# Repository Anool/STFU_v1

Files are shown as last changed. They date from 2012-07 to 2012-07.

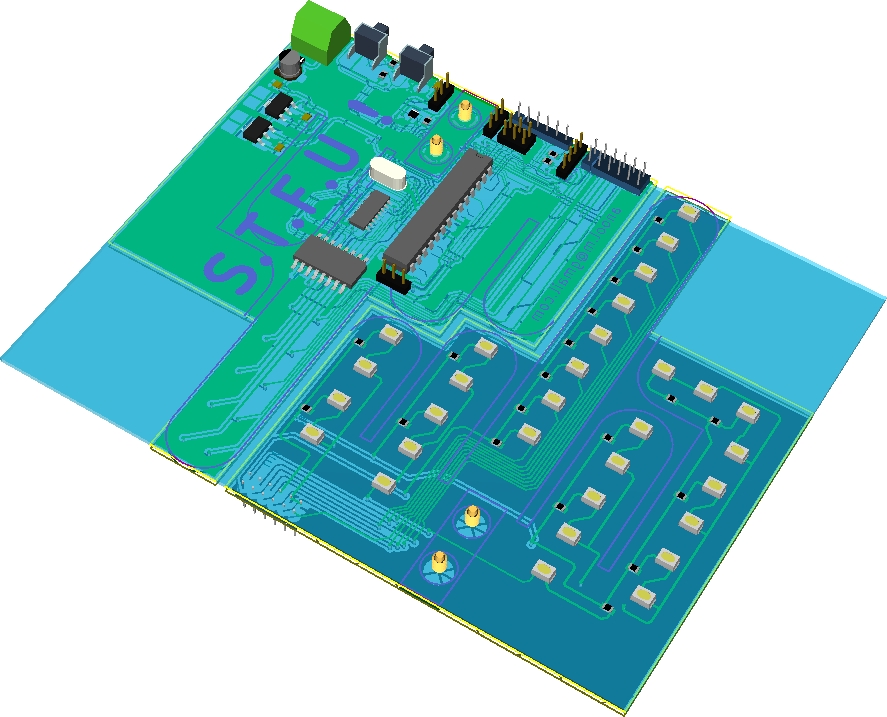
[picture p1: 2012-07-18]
stfu_Images/STFU_01.jpg

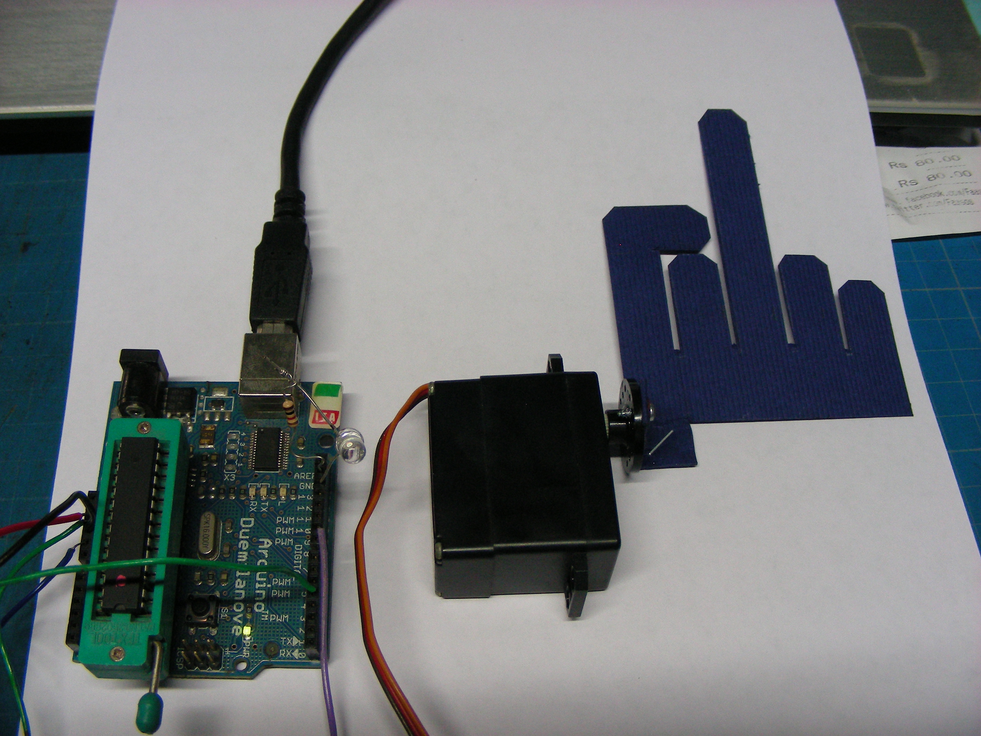
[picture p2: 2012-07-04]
stfu_Images/DSCN9575.JPG

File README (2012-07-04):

Anool J M : anool.m@gmail.com

<< inspired by an original idea from Ranjeet Walunj, @iMayavi)

<<<<<<< HEAD
1. STFU is an Arduino controlled Visual Indicator for Vehicles
2. When the STFU button is pressed, it uses a SERVO to raise up a "graphic" element and a set of LED's to light up the "graphic" element for a pre-determined time
3. One bank of eight LED's can be individually controlled to perform patterns such as running lights
4. The balance 22 LED's can be controlled as a second block with PWM patterns
5. A 3 to 8 way multiplexer allows us to control 8 LED's using 3 control pins
6. To view projcect files, you need KiCad. All KiCad files are plain text, but it won't make much sense opening them in a Text Editor
=======
1. STFU is an Arduino controlled Visual Indicator for Vehicles.
2. When the STFU button is pressed, it uses a SERVO to raise up a "graphic" element and a set of LED's to light up the "graphic" element for a pre-determined time.
3. One bank of eight LED's can be individually controlled to perform patterns such as running lights.
4. The balance 22 LED's can be controlled as a second block with PWM patterns.
5. A 3 to 8 way multiplexer allows us to control 8 LED's using 3 control pins.
>>>>>>> 4a03729d931463e6f3bd782e6f7c42ccaf4bf629

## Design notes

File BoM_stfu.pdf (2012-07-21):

STFU_v1 : Parts List + Cost

Id | Reference | Value | Manufacturer | Mfr. P/N | Vendor | Vendor P/N | QTY | RATE | AMOUNT
1 | BT1 | 2x 2032 | MPD (Memory Protection Devices) | BHX2-2032-SM | | BHX2-2032-SM-ND | 1 | 0.49 | 0.49

2

3 | | 100n | Kemet | C0805C104K3RACTU | | 399-1168-1-ND | 7 | 0.07 | 0.49
4 | C3 | 100u | Nichicon | UCL1E101MCL1GS | | 493-3937-1-ND | 1 | 0.87 | 0.87
5 | C9 | 1n | AVX Corporation | 08053A102KAT2A | | 478-6218-1-ND | 1 | 0.24 | 0.24
6 C10 | 47n | Taiyo Yuden | TMK212B7473KD-T | 587-1280-1-ND | 1 | 0.10 | 0.10
7 | D1 to D60 | LED | Cree Inc | CLM3C-WKW-CWBYA453 | | CLM3C-WKW-CWBYA453CT-ND | 60 | 0.25 | 15.00
8 D61 | Z15V | ON Semiconductor | MM3Z15VT1G | MM3Z15VT1GOSCT-ND | 1 | 0.16 | 0.16
9 D62 | LED | TT Electronics/Optek Technology | OVLGS0C8B9 | 365-1189-ND | 1 | 0.13 | 0.13
10 D63 | PWR | OSRAM Opto Semiconductors Inc | LG R971-KN-1-0-20-R18 | 475-1410-1-ND | 1 | 0.09 | 0.09
11 | D64 | IR LED | Kingbright Corp | WP710A10F3C | | 754-1600-ND | 1 | 0.26 | 0.26
12 IR1 | IRSENSOR | Sharp Microelectronics | GP1UX311QS | 425-2528-ND | 1 | 0.96 | 0.96
13 K1 | FTDI | Sullins Connector Solutions | PREC040SAAN-RC | S1012EC-40-ND | 1 | 0.51 | 0.51
14 K2 | ISP | -- | -- | -- | -- | 1 | 0.00 | 0.00
15 K3 | I2C | -- | -- | -- | -- | 1 | 0.00 | 0.00
16 K4 | SERVO | -- | -- | -- | -- | 1 | 0.00 | 0.00
17 K5 | V_SEL | -- | -- | -- | -- | 1 | 0.00 | 0.00
18 P1,P2,P8,P9 | CONN_1 | -- | -- | -- | -- | 4 | 0.00 | 0.00
19 P3,P5 | HAND_HI | -- | -- | -- | -- | 2 | 0.00 | 0.00
20 P4,P6 | HAND_LO | -- | -- | -- | -- | 2 | 0.00 | 0.00
21 P7 | BATT_12V | On Shore Technology Inc | OSTTA024163 | ED2580-ND | 1 | 0.45 | 0.45
22 P10 | MOD | -- | -- | -- | -- | 0 | 0.45 | 0.00
23 Q1 | PNP | NXP Semiconductors | PBSS9110Z,135 | 568-6798-1-ND | 1 | 0.44 | 0.44

DigiKey (http://www.digikey.com/product-detail/en/BHX2-2032-SM/BHX2-2032-SM-ND/2194763)

C1,C2,C4,C5,C6,C7,
C8

DigiKey (http://www.digikey.com/product-detail/en/C0805C104K3RACTU/399-1168-1-ND/411443)
DigiKey (http://www.digikey.com/product-detail/en/UCL1E101MCL1GS/493-3937-1-ND/2300364)
DigiKey (http://www.digikey.com/product-detail/en/08053A102KAT2A/478-6218-1-ND/2391417)
DigiKey (http://www.digikey.com/product-detail/en/TMK212B7473KD-T/587-1280-1-ND/931057)
DigiKey (http://www.digikey.com/product-detail/en/CLM3C-WKW-CWBYA453/CLM3C-WKW-CWBYA453CT-ND/1987483)
DigiKey (http://www.digikey.com/product-detail/en/MM3Z15VT1G/MM3Z15VT1GOSCT-ND/1139780)
DigiKey (http://www.digikey.com/product-detail/en/OVLGS0C8B9/365-1189-ND/827125)
DigiKey (http://www.digikey.com/product-detail/en/LG%20R971-KN-1-0-20-R18/475-1410-1-ND/1802598)
DigiKey (http://www.digikey.com/product-detail/en/WP710A10F3C/754-1600-ND/2769807)
DigiKey (http://www.digikey.com/product-detail/en/GP1UX311QS/425-2528-ND/1302212)
DigiKey (http://www.digikey.com/product-detail/en/PREC040SAAN-RC/S1012EC-40-ND/2774814)

DigiKey (http://www.digikey.com/product-detail/en/OSTTA024163/ED2580-ND/614529?cur=USD)

DigiKey (http://www.digikey.com/product-detail/en/PBSS9110Z,135/568-6798-1-ND/2676838)

24 Q2 | NPN | Fairchild Semiconductor | 2N3904BU | | 2N3904FS-ND | 1 | 0.18 | 0.18
25 R1,R4,R38,R39 | 10k | Stackpole Electronics Inc | RMCF0805JT10K0 | | RMCF0805JT10K0CT-ND | 4 | 0.03 | 0.12
26 | 120E | Stackpole Electronics Inc | RMCF0805JT120R | | RMCF0805JT120RCT-ND | 34 | 0.03 | 1.02
27 R3 | 1k | Stackpole Electronics Inc | RMCF0805JT1K00 | | RMCF0805JT1K00CT-ND | 1 | 0.03 | 0.03
28 R5 | 10k | Copal Electronics Inc | CT94EP203 | | CT94EP203-ND | 1 | 0.02 | 0.02
29 R42 | 47E | Stackpole Electronics Inc | RMCF0603JT47R0 | | RMCF0603JT47R0CT-ND | 1 | 0.02 | 0.02
30 R43 | 220E | Stackpole Electronics Inc | RMCF0603JT220R | | RMCF0603JT220RCT-ND | 1 | 1.30 | 1.30
31 R7 | 15k | Stackpole Electronics Inc | RMCF0805JT15K0 | | RMCF0805JT15K0CT-ND | 1 | 0.03 | 0.03
32 SW1 | SW_STFU | NKK Switches | HP0215AFKP2-S | | HP0215AFKP2-S-ND | 1 | 0.75 | 0.75
33 SW2 | RST | TE Connectivity | FSM2JH | | 450-1649-ND | 1 | 0.20 | 0.20
34 SW3 | SW_ENT | TE Connectivity | FSM2JH | | 450-1649-ND | 1 | 0.20 | 0.20
35 | CONN_1 | -- | -- | -- | -- | 6 | 0.00 | 0.00
36 U1 | ATMEGA328-P | Atmel | ATMEGA328-PU | | ATMEGA328-PU-ND | 1 | 2.88 | 2.88
37 U2 | HEF4051B | NXP Semiconductors | HEF4051BT,652 | | 568-3979-5-ND | 1 | 0.49 | 0.49
38 U3 | ULN2803 | Texas Instruments | ULN2803ADWR | | 296-15777-1-ND | 1 | 0.90 | 0.90
39 U4 | 7809 | STMicroelectronics | L7809CD2T-TR | | 497-1176-1-ND | 1 | 0.67 | 0.67
40 U5 | 7805 | ON Semiconductor | NCP1117DT50G | | NCP1117DT50GOS-ND | 1 | 0.48 | 0.48
41 U6 | NE555 | STMicroelectronics | NE555DT | | 497-1962-1-ND | 1 | 0.41 | 0.41
42 X1 | 16MHz | ECS Inc | ZTT-16.00MX | | X908-ND | 1 | 0.70 | 0.70
| | | | | Shipping | | | 14.00
| | | | | Total, Parts (1 kit), US$ | | | 44.59

OTHER PARTS
SV1 | SERVO | Vigor | VTS-08B | 1 | 9.17 | 9.17
| Connection Flat Cable | | | 1 | 0.83 | 0.83

DigiKey (http://www.digikey.com/product-detail/en/2N3904BU/2N3904FS-ND/1413)
DigiKey (http://www.digikey.com/product-detail/en/RMCF0805JT10K0/RMCF0805JT10K0CT-ND/1942577)
R2, R6, R8 to R37,
R40, R41

DigiKey (http://www.digikey.com/product-detail/en/RMCF0805JT120R/RMCF0805JT120RCT-ND/1942540)
DigiKey (http://www.digikey.com/product-detail/en/RMCF0805JT1K00/RMCF0805JT1K00CT-ND/1942557)
DigiKey (http://www.digikey.com/product-detail/en/CT94EP203/CT94EP203-ND/738374)
DigiKey (http://www.digikey.com/product-detail/en/RMCF0603JT47R0/RMCF0603JT47R0CT-ND/1943152)
DigiKey (http://www.digikey.com/product-detail/en/RMCF0603JT220R/RMCF0603JT220RCT-ND/1943162)
DigiKey (http://www.digikey.com/product-detail/en/RMCF0805JT15K0/RMCF0805JT15K0CT-ND/1942578)
DigiKey (http://www.digikey.com/scripts/dksearch/dksus.dll?vendor=0&keywords=HP0215AFKP2-S-ND)
DigiKey
DigiKey (http://www.digikey.com/product-detail/en/FSM2JH/450-1649-ND/1632535?cur=USD)
TP1,TP2,TP3,TP4,T
5,T6
DigiKey (http://www.digikey.com/scripts/dksearch/dksus.dll?vendor=0&keywords=ATMEGA328-PU-ND)
DigiKey (http://www.digikey.com/product-detail/en/HEF4051BT,652/568-3979-5-ND/763572)
DigiKey (http://www.digikey.com/product-detail/en/ULN2803ADWR/296-15777-1-ND/598088)
DigiKey (http://www.digikey.com/product-detail/en/L7809CD2T-TR/497-1176-1-ND/586176)
DigiKey (http://www.digikey.com/product-detail/en/NCP1117DT50G/NCP1117DT50GOS-ND/1483320)
DigiKey (http://www.digikey.com/product-detail/en/NE555DT/497-1962-1-ND/599128)
DigiKey (http://www.digikey.com/product-detail/en/ZTT-16.00MX/X908-ND/170095?cur=USD)

RoboSoft Systems (http://www.robosoftsystems.co.in/roboshop/index.php/motor-accessories/servo-stepper-motors/vts-08b.html)

Mounting Bracket | 1 | 8.33 | 8.33
Hardware | 1 | 1.67 | 1.67
Acrylic (Laser cut) | 1 | 8.33 | 8.33
PCB1 | PCB | OSHPark.com | 2 layers, 6.02x4.77 in. (153x121mm). $143.35 for set of three plus Shipping | 1 55.00 | 55.00
| | | TOTAL, US$ | | 83.33
| | | TOTAL, US$ | | 127.92
| | | TOTAL, ` , @ | 60 | 7675.40

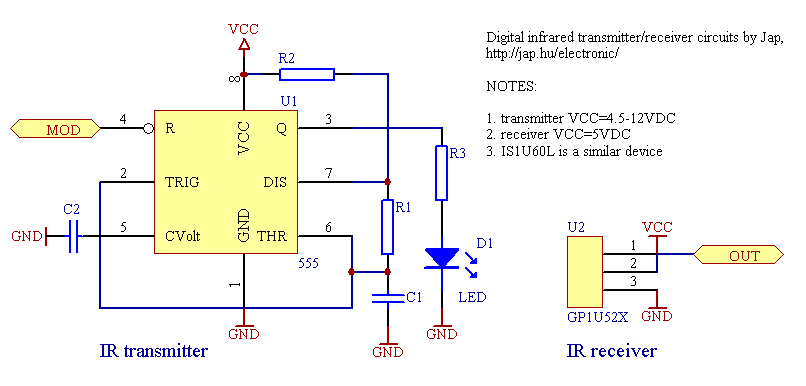
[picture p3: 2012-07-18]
stfu_Images/httpjap.huelectronicir.gif

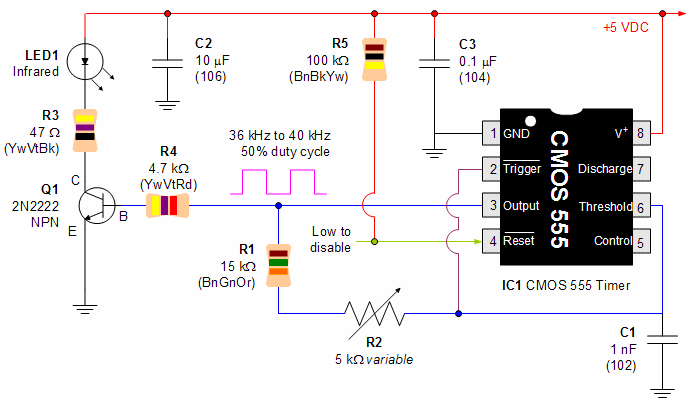
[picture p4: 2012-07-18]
stfu_Images/Infrared-emitter-38kHz-555-timer-circuit-schematic.gif

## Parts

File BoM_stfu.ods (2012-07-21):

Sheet: BoM_STFU
STFU_v1 : Parts List + Cost
Id | Reference | Value | Manufacturer | Mfr. P/N | Vendor | Vendor P/N | QTY | RATE | AMOUNT
1 | BT1 | 2x 2032 | MPD (Memory Protection Devices) | BHX2-2032-SM | DigiKey (http://www.digikey.com/product-detail/en/BHX2-2032-SM/BHX2-2032-SM-ND/2194763) | BHX2-2032-SM-ND | 1 | 0.49 | 0.49
2
3 | C1,C2,C4,C5,C6,C7,C8 | 100n | Kemet | C0805C104K3RACTU | DigiKey (http://www.digikey.com/product-detail/en/C0805C104K3RACTU/399-1168-1-ND/411443) | 399-1168-1-ND | 7 | 0.07 | 0.49
4 | C3 | 100u | Nichicon | UCL1E101MCL1GS | DigiKey (http://www.digikey.com/product-detail/en/UCL1E101MCL1GS/493-3937-1-ND/2300364) | 493-3937-1-ND | 1 | 0.87 | 0.87
5 | C9 | 1n | AVX Corporation | 08053A102KAT2A | DigiKey (http://www.digikey.com/product-detail/en/08053A102KAT2A/478-6218-1-ND/2391417) | 478-6218-1-ND | 1 | 0.24 | 0.24
6 | C10 | 47n | Taiyo Yuden | TMK212B7473KD-T | DigiKey (http://www.digikey.com/product-detail/en/TMK212B7473KD-T/587-1280-1-ND/931057) | 587-1280-1-ND | 1 | 0.10 | 0.10
7 | D1 to D60 | LED | Cree Inc | CLM3C-WKW-CWBYA453 | DigiKey (http://www.digikey.com/product-detail/en/CLM3C-WKW-CWBYA453/CLM3C-WKW-CWBYA453CT-ND/1987483) | CLM3C-WKW-CWBYA453CT-ND | 60 | 0.25 | 15.00
8 | D61 | Z15V | ON Semiconductor | MM3Z15VT1G | DigiKey (http://www.digikey.com/product-detail/en/MM3Z15VT1G/MM3Z15VT1GOSCT-ND/1139780) | MM3Z15VT1GOSCT-ND | 1 | 0.16 | 0.16
9 | D62 | LED | TT Electronics/Optek Technology | OVLGS0C8B9 | DigiKey (http://www.digikey.com/product-detail/en/OVLGS0C8B9/365-1189-ND/827125) | 365-1189-ND | 1 | 0.13 | 0.13
10 | D63 | PWR | OSRAM Opto Semiconductors Inc | LG R971-KN-1-0-20-R18 | DigiKey (http://www.digikey.com/product-detail/en/LG%20R971-KN-1-0-20-R18/475-1410-1-ND/1802598) | 475-1410-1-ND | 1 | 0.09 | 0.09
11 | D64 | IR LED | Kingbright Corp | WP710A10F3C | DigiKey (http://www.digikey.com/product-detail/en/WP710A10F3C/754-1600-ND/2769807) | 754-1600-ND | 1 | 0.26 | 0.26
12 | IR1 | IRSENSOR | Sharp Microelectronics | GP1UX311QS | DigiKey (http://www.digikey.com/product-detail/en/GP1UX311QS/425-2528-ND/1302212) | 425-2528-ND | 1 | 0.96 | 0.96
13 | K1 | FTDI | Sullins Connector Solutions | PREC040SAAN-RC | DigiKey (http://www.digikey.com/product-detail/en/PREC040SAAN-RC/S1012EC-40-ND/2774814) | S1012EC-40-ND | 1 | 0.51 | 0.51
14 | K2 | ISP | -- | -- | -- | -- | 1 | 0.00 | 0.00
15 | K3 | I2C | -- | -- | -- | -- | 1 | 0.00 | 0.00
16 | K4 | SERVO | -- | -- | -- | -- | 1 | 0.00 | 0.00
17 | K5 | V_SEL | -- | -- | -- | -- | 1 | 0.00 | 0.00
18 | P1,P2,P8,P9 | CONN_1 | -- | -- | -- | -- | 4 | 0.00 | 0.00
19 | P3,P5 | HAND_HI | -- | -- | -- | -- | 2 | 0.00 | 0.00
20 | P4,P6 | HAND_LO | -- | -- | -- | -- | 2 | 0.00 | 0.00
21 | P7 | BATT_12V | On Shore Technology Inc | OSTTA024163 | DigiKey (http://www.digikey.com/product-detail/en/OSTTA024163/ED2580-ND/614529?cur=USD) | ED2580-ND | 1 | 0.45 | 0.45
22 | P10 | MOD | -- | -- | -- | -- | 0 | 0.45 | 0.00
23 | Q1 | PNP | NXP Semiconductors | PBSS9110Z,135 | DigiKey (http://www.digikey.com/product-detail/en/PBSS9110Z,135/568-6798-1-ND/2676838) | 568-6798-1-ND | 1 | 0.44 | 0.44
24 | Q2 | NPN | Fairchild Semiconductor | 2N3904BU | DigiKey (http://www.digikey.com/product-detail/en/2N3904BU/2N3904FS-ND/1413) | 2N3904FS-ND | 1 | 0.18 | 0.18
25 | R1,R4,R38,R39 | 10k | Stackpole Electronics Inc | RMCF0805JT10K0 | DigiKey (http://www.digikey.com/product-detail/en/RMCF0805JT10K0/RMCF0805JT10K0CT-ND/1942577) | RMCF0805JT10K0CT-ND | 4 | 0.03 | 0.12
26 | R2, R6, R8 to R37, R40, R41 | 120E | Stackpole Electronics Inc | RMCF0805JT120R | DigiKey (http://www.digikey.com/product-detail/en/RMCF0805JT120R/RMCF0805JT120RCT-ND/1942540) | RMCF0805JT120RCT-ND | 34 | 0.03 | 1.02
27 | R3 | 1k | Stackpole Electronics Inc | RMCF0805JT1K00 | DigiKey (http://www.digikey.com/product-detail/en/RMCF0805JT1K00/RMCF0805JT1K00CT-ND/1942557) | RMCF0805JT1K00CT-ND | 1 | 0.03 | 0.03
28 | R5 | 10k | Copal Electronics Inc | CT94EP203 | DigiKey (http://www.digikey.com/product-detail/en/CT94EP203/CT94EP203-ND/738374) | CT94EP203-ND | 1 | 0.02 | 0.02
29 | R42 | 47E | Stackpole Electronics Inc | RMCF0603JT47R0 | DigiKey (http://www.digikey.com/product-detail/en/RMCF0603JT47R0/RMCF0603JT47R0CT-ND/1943152) | RMCF0603JT47R0CT-ND | 1 | 0.02 | 0.02
30 | R43 | 220E | Stackpole Electronics Inc | RMCF0603JT220R | DigiKey (http://www.digikey.com/product-detail/en/RMCF0603JT220R/RMCF0603JT220RCT-ND/1943162) | RMCF0603JT220RCT-ND | 1 | 1.30 | 1.30
31 | R7 | 15k | Stackpole Electronics Inc | RMCF0805JT15K0 | DigiKey (http://www.digikey.com/product-detail/en/RMCF0805JT15K0/RMCF0805JT15K0CT-ND/1942578) | RMCF0805JT15K0CT-ND | 1 | 0.03 | 0.03
32 | SW1 | SW_STFU | NKK Switches | HP0215AFKP2-S | DigiKey (http://www.digikey.com/scripts/dksearch/dksus.dll?vendor=0&keywords=HP0215AFKP2-S-ND) | HP0215AFKP2-S-ND | 1 | 0.75 | 0.75
33 | SW2 | RST | TE Connectivity | FSM2JH | DigiKey (http://www.digikey.com/product-detail/en/FSM2JH/450-1649-ND/1632535?cur=USD) | 450-1649-ND | 1 | 0.20 | 0.20
34 | SW3 | SW_ENT | TE Connectivity | FSM2JH | DigiKey (http://www.digikey.com/product-detail/en/FSM2JH/450-1649-ND/1632535?cur=USD) | 450-1649-ND | 1 | 0.20 | 0.20
35 | TP1,TP2,TP3,TP4,T5,T6 | CONN_1 | -- | -- | -- | -- | 6 | 0.00 | 0.00
36 | U1 | ATMEGA328-P | Atmel | ATMEGA328-PU | DigiKey (http://www.digikey.com/scripts/dksearch/dksus.dll?vendor=0&keywords=ATMEGA328-PU-ND) | ATMEGA328-PU-ND | 1 | 2.88 | 2.88
37 | U2 | HEF4051B | NXP Semiconductors | HEF4051BT,652 | DigiKey (http://www.digikey.com/product-detail/en/HEF4051BT,652/568-3979-5-ND/763572) | 568-3979-5-ND | 1 | 0.49 | 0.49
38 | U3 | ULN2803 | Texas Instruments | ULN2803ADWR | DigiKey (http://www.digikey.com/product-detail/en/ULN2803ADWR/296-15777-1-ND/598088) | 296-15777-1-ND | 1 | 0.90 | 0.90
39 | U4 | 7809 | STMicroelectronics | L7809CD2T-TR | DigiKey (http://www.digikey.com/product-detail/en/L7809CD2T-TR/497-1176-1-ND/586176) | 497-1176-1-ND | 1 | 0.67 | 0.67
40 | U5 | 7805 | ON Semiconductor | NCP1117DT50G | DigiKey (http://www.digikey.com/product-detail/en/NCP1117DT50G/NCP1117DT50GOS-ND/1483320) | NCP1117DT50GOS-ND | 1 | 0.48 | 0.48
41 | U6 | NE555 | STMicroelectronics | NE555DT | DigiKey (http://www.digikey.com/product-detail/en/NE555DT/497-1962-1-ND/599128) | 497-1962-1-ND | 1 | 0.41 | 0.41
42 | X1 | 16MHz | ECS Inc | ZTT-16.00MX | DigiKey (http://www.digikey.com/product-detail/en/ZTT-16.00MX/X908-ND/170095?cur=USD) | X908-ND | 1 | 0.70 | 0.70
 |  |  |  |  |  | Shipping |  |  | 14.00
 |  |  |  |  |  | Total, Parts (1 kit), US$ |  |  | 44.59
 | OTHER PARTS
 | SV1 | SERVO | Vigor | VTS-08B | RoboSoft Systems (http://www.robosoftsystems.co.in/roboshop/index.php/motor-accessories/servo-stepper-motors/vts-08b.html) |  | 1 | 9.17 | 9.17
 |  | Connection Flat Cable |  |  |  |  | 1 | 0.83 | 0.83
 |  | Mounting Bracket |  |  |  |  | 1 | 8.33 | 8.33
 |  | Hardware |  |  |  |  | 1 | 1.67 | 1.67
 |  | Acrylic (Laser cut) |  |  |  |  | 1 | 8.33 | 8.33
 | PCB1 | PCB | OSHPark.com | 2 layers, 6.02x4.77 in. (153x121mm). $143.35 for set of three plus Shipping |  |  | 1 | 55.00 | 55.00
 |  |  |  |  |  | TOTAL, US$ |  |  | 83.33
 |  |  |  |  |  | TOTAL, US$ |  |  | 127.92
 |  |  |  |  |  | TOTAL, ` , @ | 60 |  | 7675.40

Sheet: Sheet4
Reference | Quantity | Manufacturer | Mfr. P/N | Vendor | Vendor P/N
BT1 | 1 | MPD (Memory Protection Devices) | BHX2-2032-SM | DigiKey (http://www.digikey.com/product-detail/en/BHX2-2032-SM/BHX2-2032-SM-ND/2194763) | BHX2-2032-SM-ND
C1,C2,C4,C5,C6,C7,C8 | 7 | Kemet | C0805C104K3RACTU | DigiKey (http://www.digikey.com/product-detail/en/C0805C104K3RACTU/399-1168-1-ND/411443) | 399-1168-1-ND
C3 | 1 | Nichicon | UCL1E101MCL1GS | DigiKey (http://www.digikey.com/product-detail/en/UCL1E101MCL1GS/493-3937-1-ND/2300364) | 493-3937-1-ND
C9 | 1 | AVX Corporation | 08053A102KAT2A | DigiKey (http://www.digikey.com/product-detail/en/08053A102KAT2A/478-6218-1-ND/2391417) | 478-6218-1-ND
C10 | 1 | Taiyo Yuden | TMK212B7473KD-T | DigiKey (http://www.digikey.com/product-detail/en/TMK212B7473KD-T/587-1280-1-ND/931057) | 587-1280-1-ND
D1 to D60 | 60 | Cree Inc | CLM3C-WKW-CWBYA453 | DigiKey (http://www.digikey.com/product-detail/en/CLM3C-WKW-CWBYA453/CLM3C-WKW-CWBYA453CT-ND/1987483) | CLM3C-WKW-CWBYA453CT-ND
D61 | 1 | ON Semiconductor | MM3Z15VT1G | DigiKey (http://www.digikey.com/product-detail/en/MM3Z15VT1G/MM3Z15VT1GOSCT-ND/1139780) | MM3Z15VT1GOSCT-ND
D63 | 1 | OSRAM Opto Semiconductors Inc | LG R971-KN-1-0-20-R18 | DigiKey (http://www.digikey.com/product-detail/en/LG%20R971-KN-1-0-20-R18/475-1410-1-ND/1802598) | 475-1410-1-ND
D64 | 1 | Kingbright Corp | WP710A10F3C | DigiKey (http://www.digikey.com/product-detail/en/WP710A10F3C/754-1600-ND/2769807) | 754-1600-ND
K1 | 1 | Sullins Connector Solutions | PREC040SAAN-RC | DigiKey (http://www.digikey.com/product-detail/en/PREC040SAAN-RC/S1012EC-40-ND/2774814) | S1012EC-40-ND
Q1 | 1 | NXP Semiconductors | PBSS9110Z,135 | DigiKey (http://www.digikey.com/product-detail/en/PBSS9110Z,135/568-6798-1-ND/2676838) | 568-6798-1-ND
Q2 | 1 | Fairchild Semiconductor | 2N3904BU | DigiKey (http://www.digikey.com/product-detail/en/2N3904BU/2N3904FS-ND/1413) | 2N3904FS-ND
R1,R4,R38,R39 | 4 | Stackpole Electronics Inc | RMCF0805JT10K0 | DigiKey (http://www.digikey.com/product-detail/en/RMCF0805JT10K0/RMCF0805JT10K0CT-ND/1942577) | RMCF0805JT10K0CT-ND
R2, R6, R8 to R37, R40, R41 | 34 | Stackpole Electronics Inc | RMCF0805JT120R | DigiKey (http://www.digikey.com/product-detail/en/RMCF0805JT120R/RMCF0805JT120RCT-ND/1942540) | RMCF0805JT120RCT-ND
R3 | 1 | Stackpole Electronics Inc | RMCF0805JT1K00 | DigiKey (http://www.digikey.com/product-detail/en/RMCF0805JT1K00/RMCF0805JT1K00CT-ND/1942557) | RMCF0805JT1K00CT-ND
R42 | 1 | Stackpole Electronics Inc | RMCF0603JT47R0 | DigiKey (http://www.digikey.com/product-detail/en/RMCF0603JT47R0/RMCF0603JT47R0CT-ND/1943152) | RMCF0603JT47R0CT-ND
R43 | 1 | Stackpole Electronics Inc | RMCF0603JT220R | DigiKey (http://www.digikey.com/product-detail/en/RMCF0603JT220R/RMCF0603JT220RCT-ND/1943162) | RMCF0603JT220RCT-ND
R7 | 1 | Stackpole Electronics Inc | RMCF0805JT15K0 | DigiKey (http://www.digikey.com/product-detail/en/RMCF0805JT15K0/RMCF0805JT15K0CT-ND/1942578) | RMCF0805JT15K0CT-ND
SW2,SW3 | 2 | TE Connectivity | FSM2JH | DigiKey (http://www.digikey.com/product-detail/en/FSM2JH/450-1649-ND/1632535?cur=USD) | 450-1649-ND
U1 | 1 | Atmel | ATMEGA328-PU | DigiKey (http://www.digikey.com/scripts/dksearch/dksus.dll?vendor=0&keywords=ATMEGA328-PU-ND) | ATMEGA328-PU-ND
U2 | 1 | NXP Semiconductors | HEF4051BT,652 | DigiKey (http://www.digikey.com/product-detail/en/HEF4051BT,652/568-3979-5-ND/763572) | 568-3979-5-ND
U3 | 1 | Texas Instruments | ULN2803ADWR | DigiKey (http://www.digikey.com/product-detail/en/ULN2803ADWR/296-15777-1-ND/598088) | 296-15777-1-ND
U4 | 1 | STMicroelectronics | L7809CD2T-TR | DigiKey (http://www.digikey.com/product-detail/en/L7809CD2T-TR/497-1176-1-ND/586176) | 497-1176-1-ND
U5 | 1 | ON Semiconductor | NCP1117DT50G | DigiKey (http://www.digikey.com/product-detail/en/NCP1117DT50G/NCP1117DT50GOS-ND/1483320) | NCP1117DT50GOS-ND
U6 | 1 | STMicroelectronics | NE555DT | DigiKey (http://www.digikey.com/product-detail/en/NE555DT/497-1962-1-ND/599128) | 497-1962-1-ND
X1 | 1 | ECS Inc | ZTT-16.00MX | DigiKey (http://www.digikey.com/product-detail/en/ZTT-16.00MX/X908-ND/170095?cur=USD) | X908-ND

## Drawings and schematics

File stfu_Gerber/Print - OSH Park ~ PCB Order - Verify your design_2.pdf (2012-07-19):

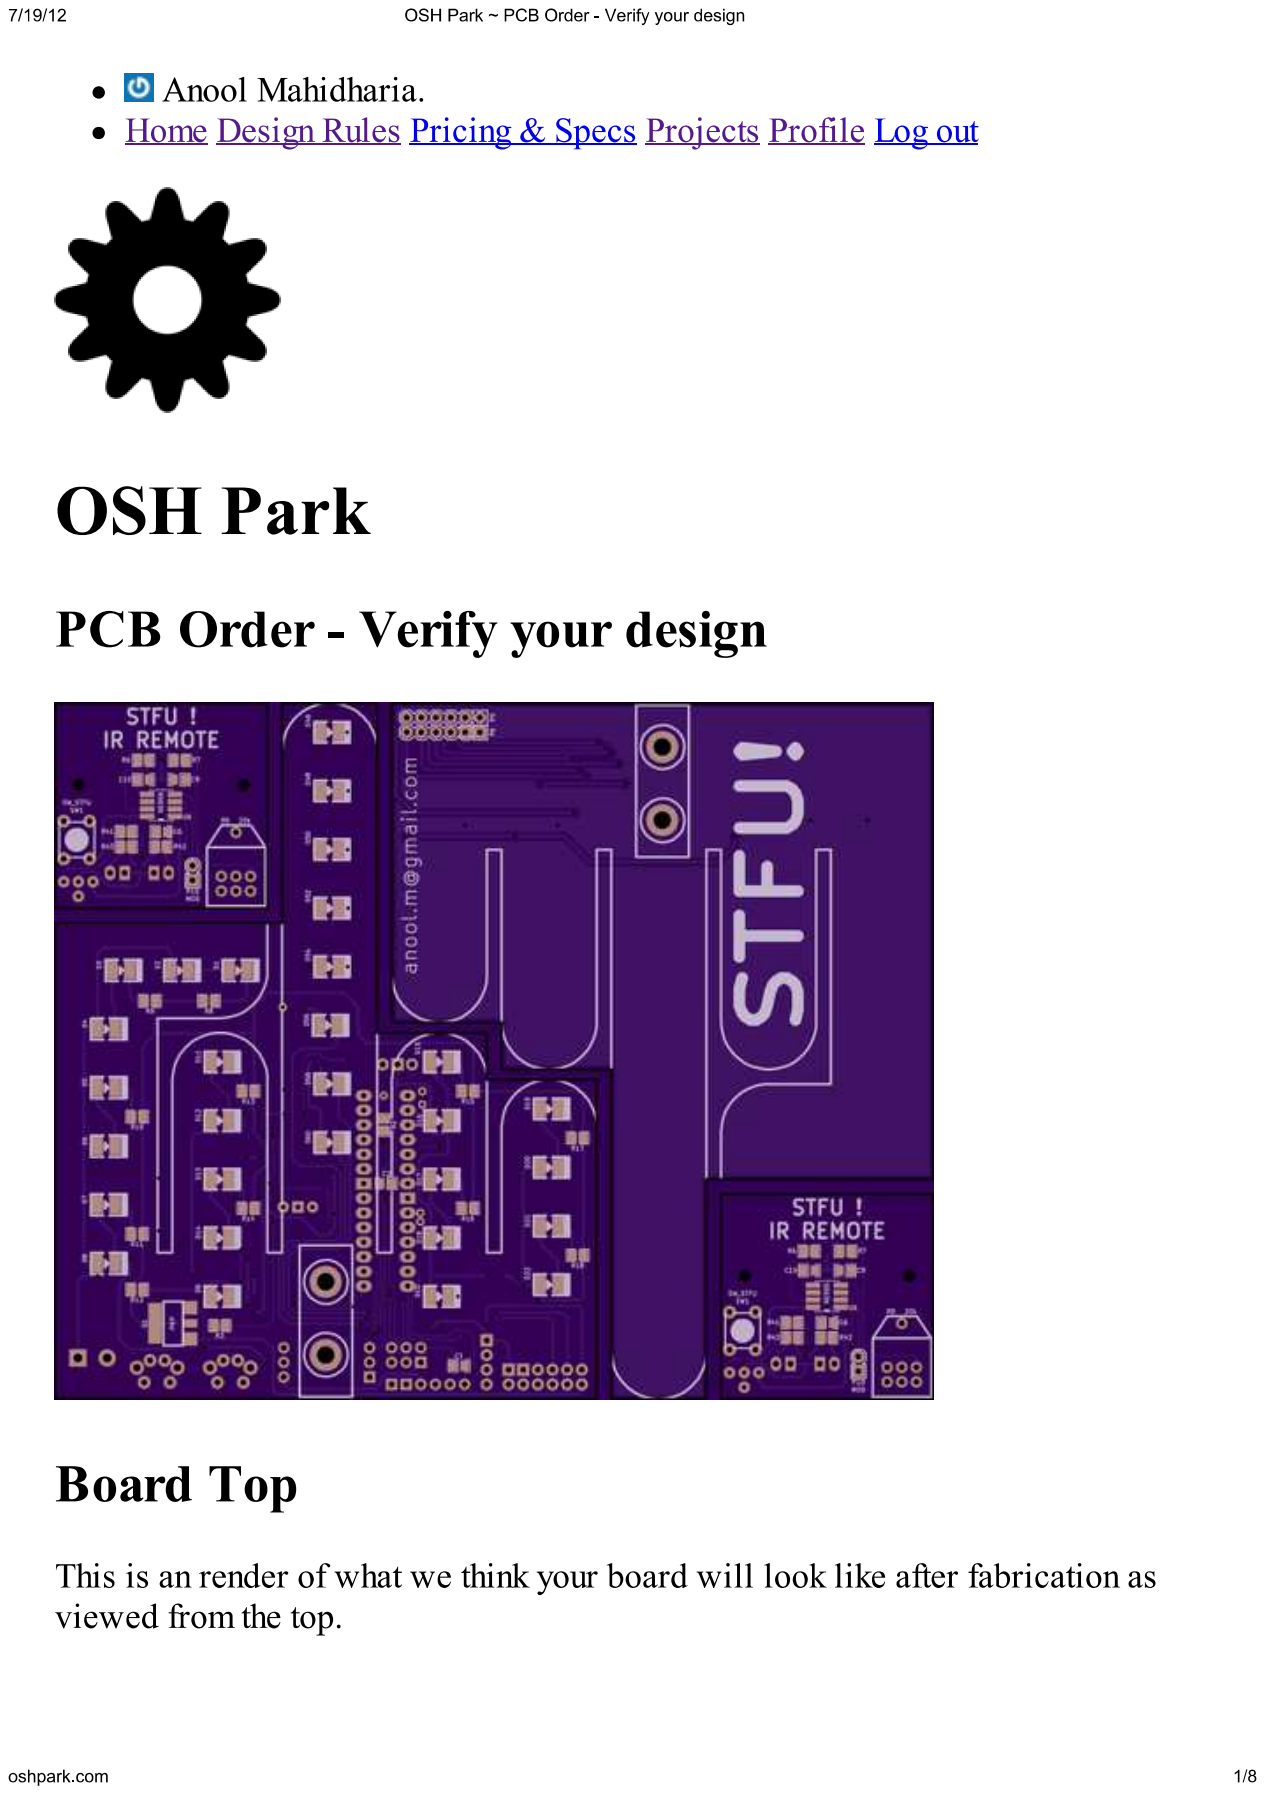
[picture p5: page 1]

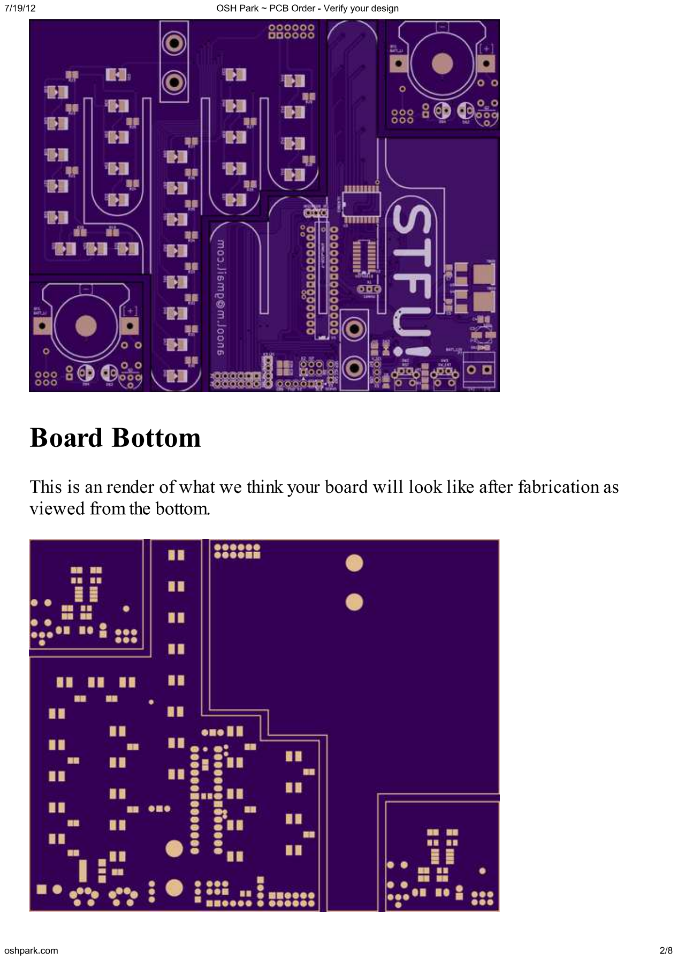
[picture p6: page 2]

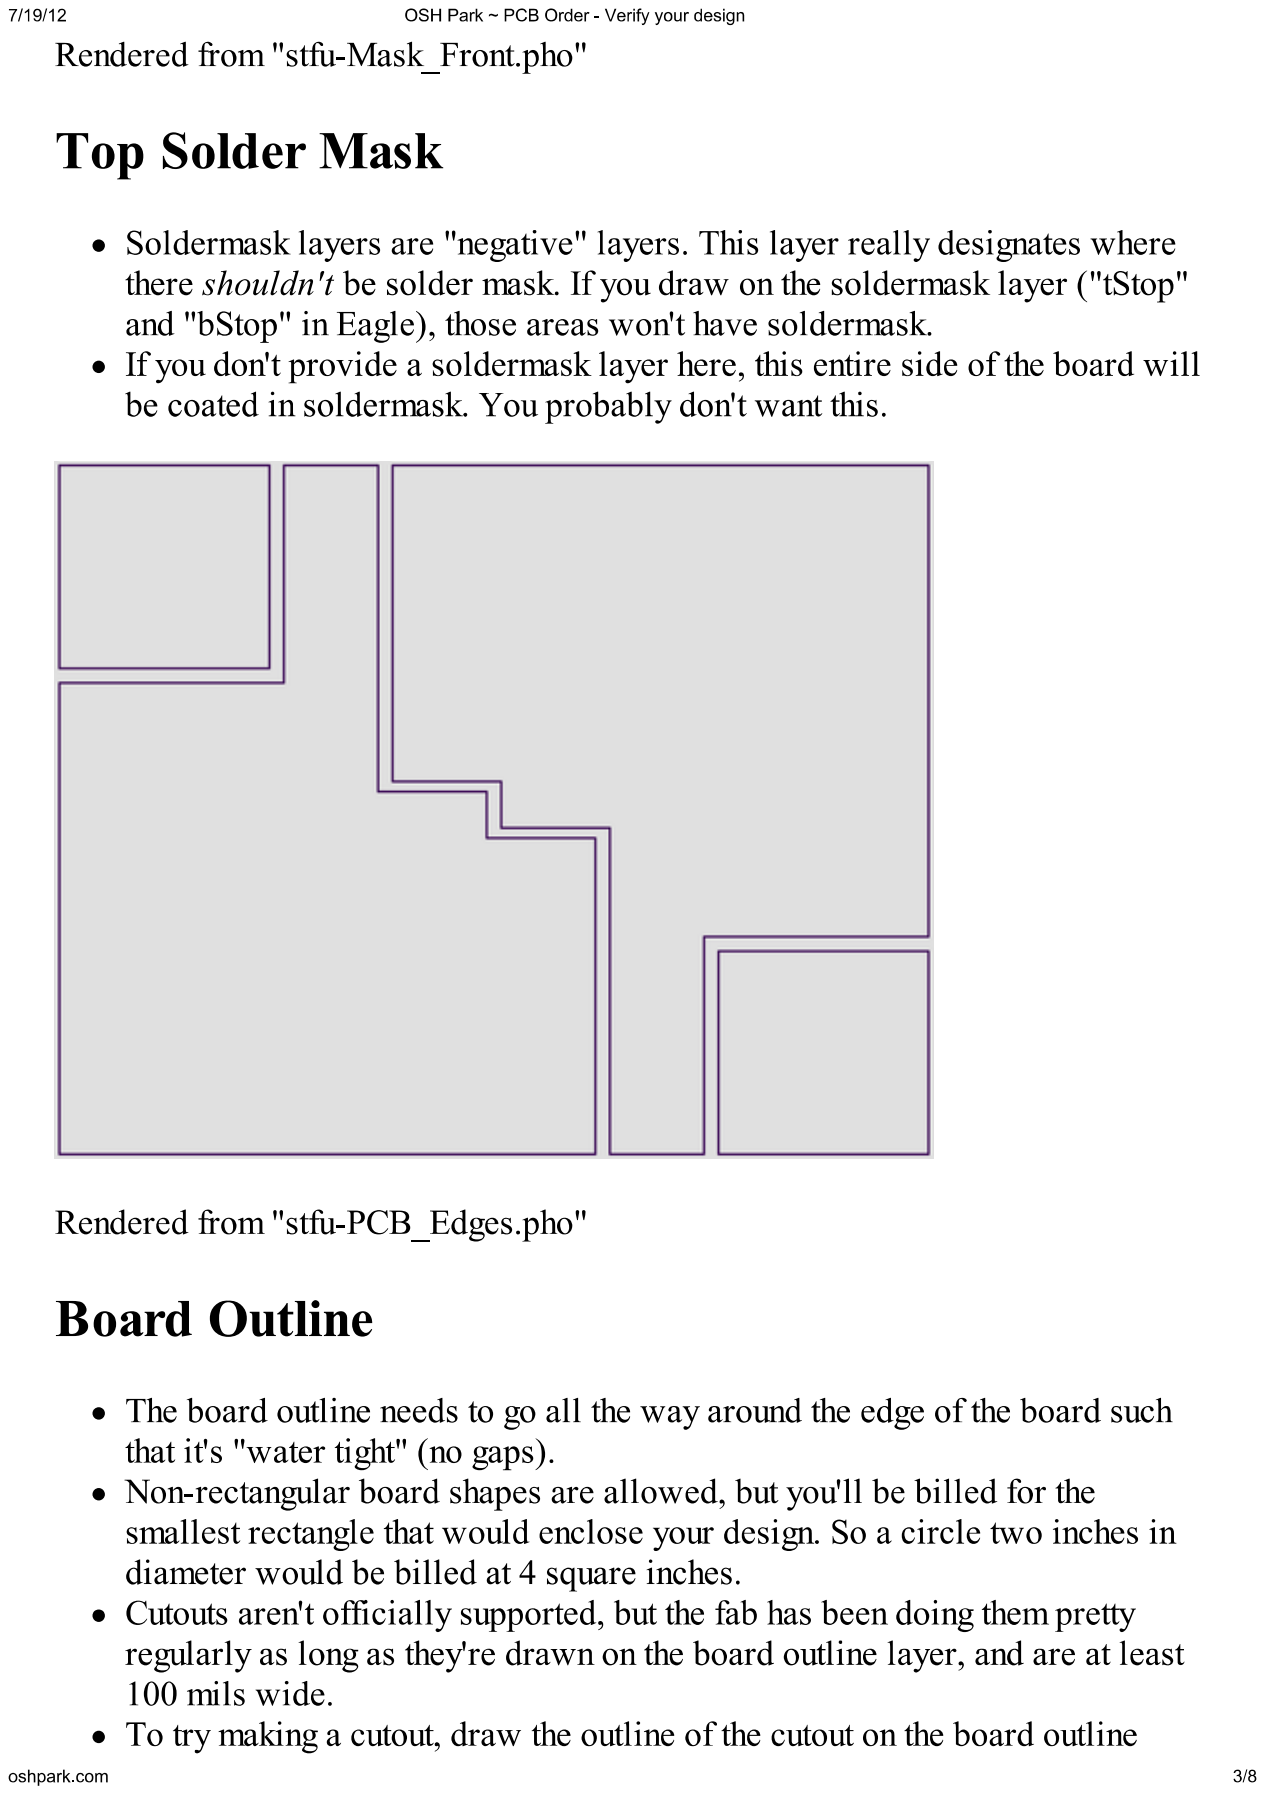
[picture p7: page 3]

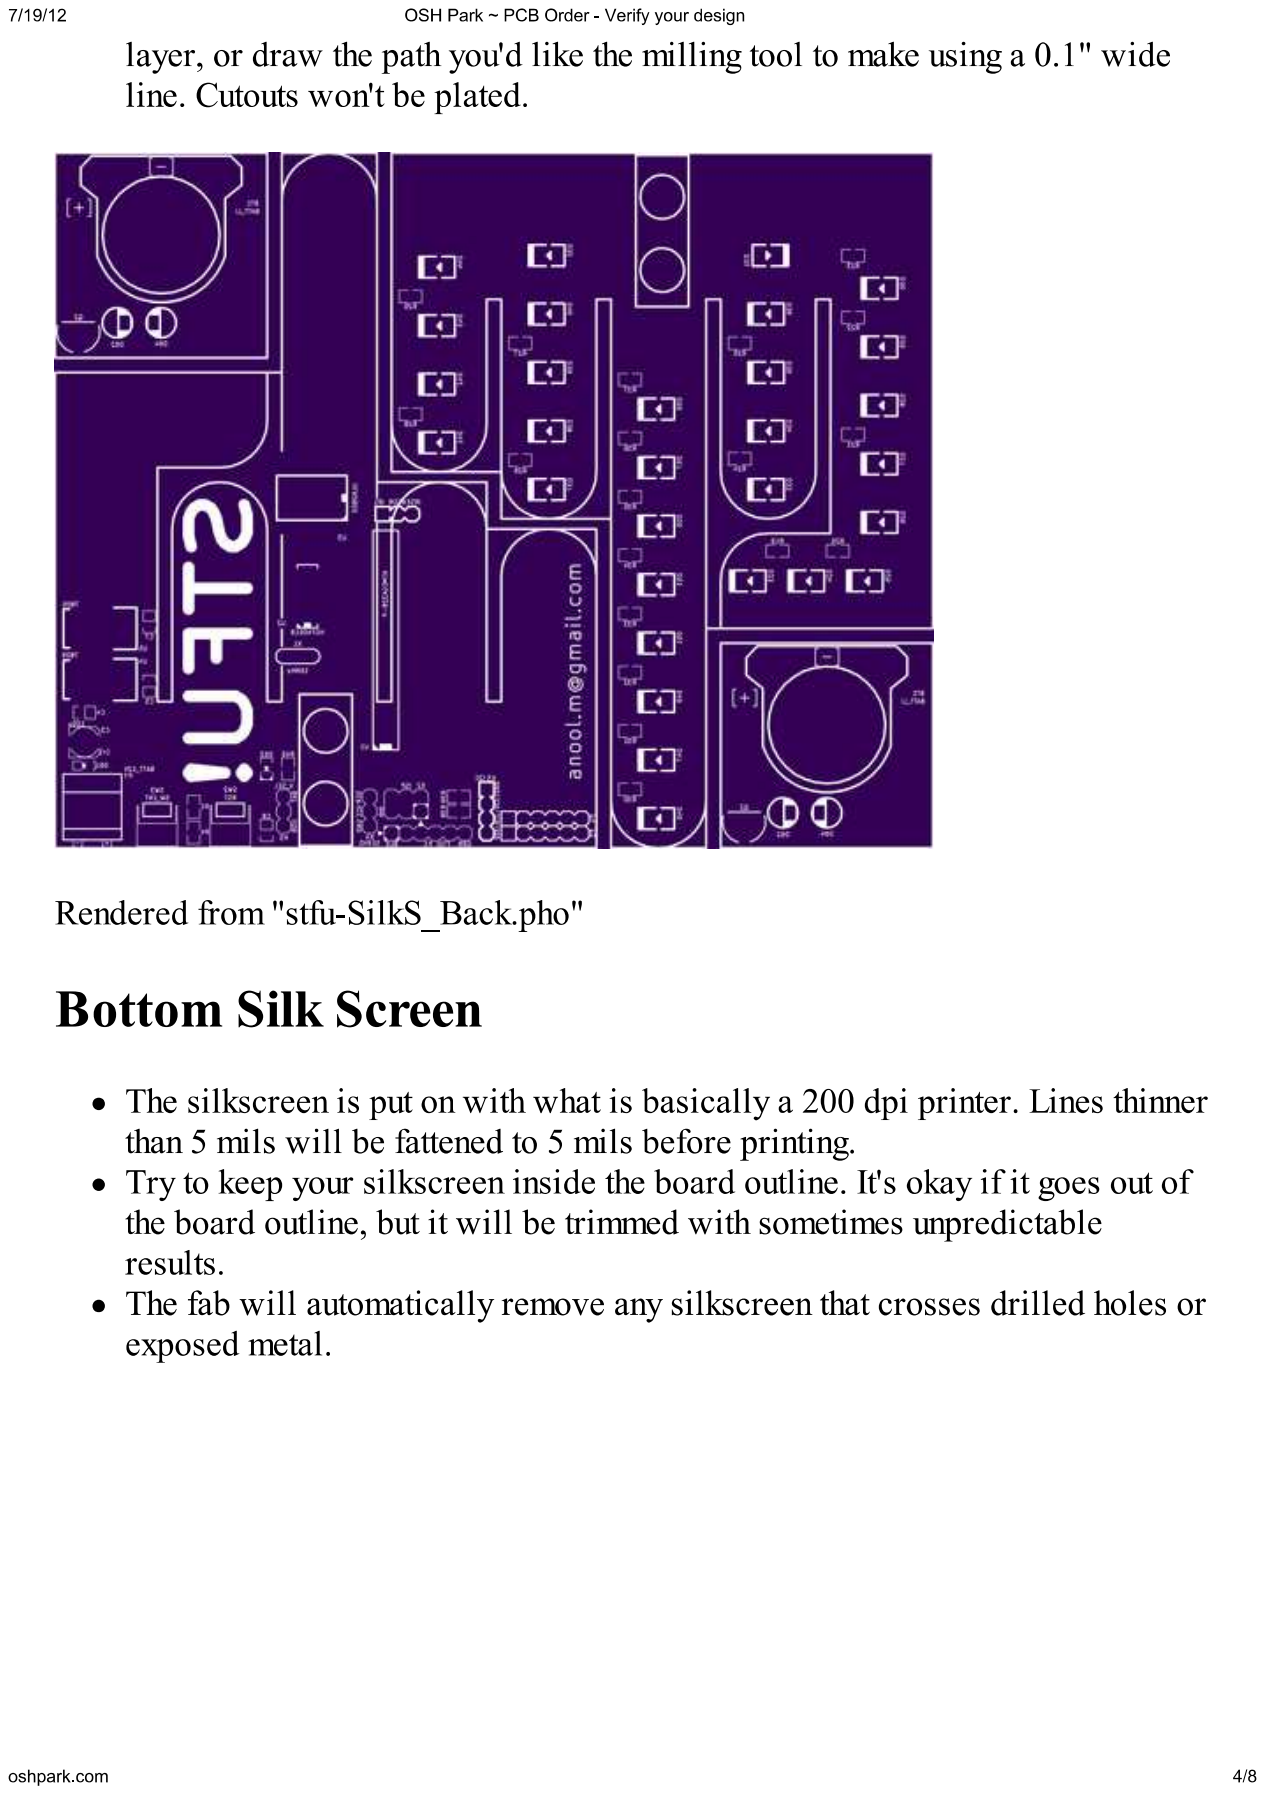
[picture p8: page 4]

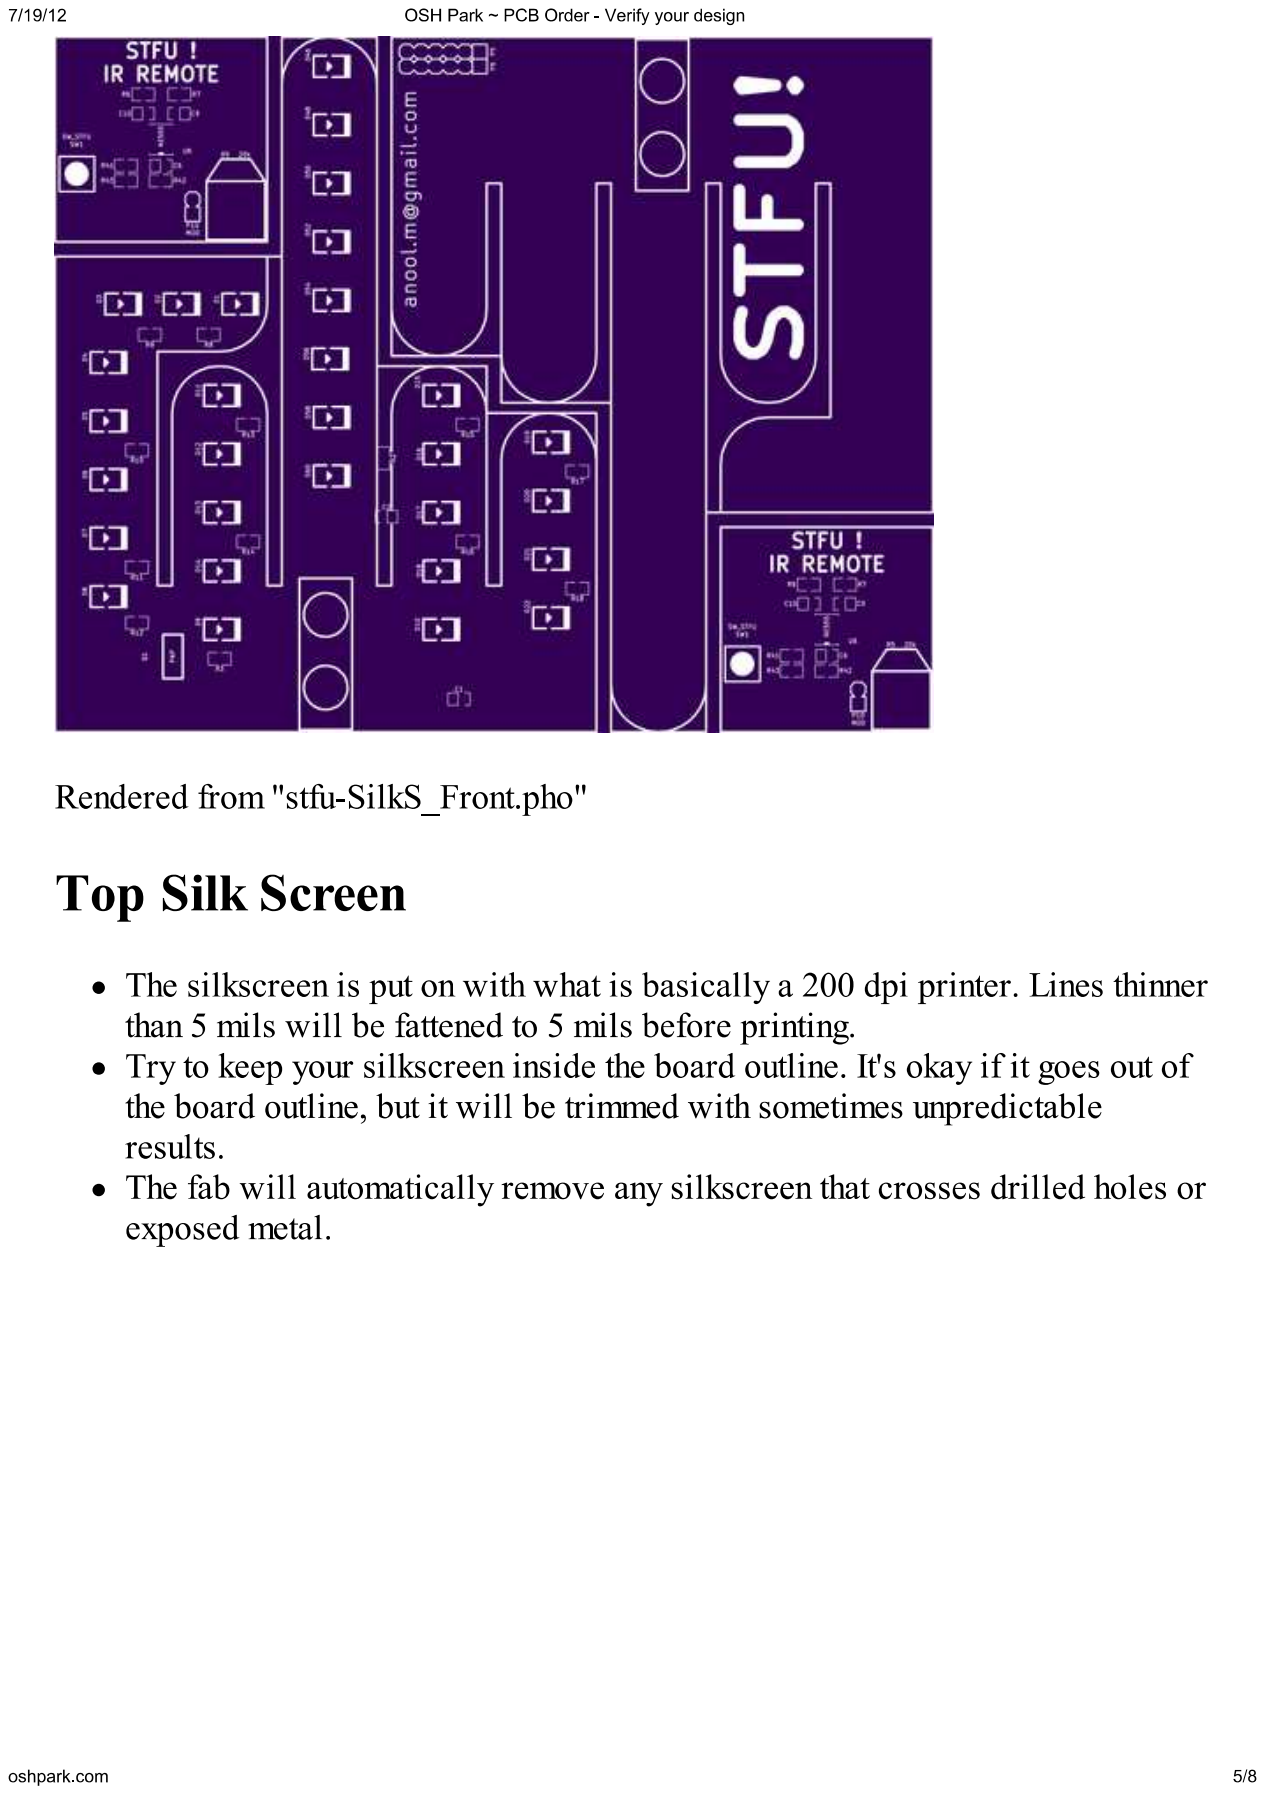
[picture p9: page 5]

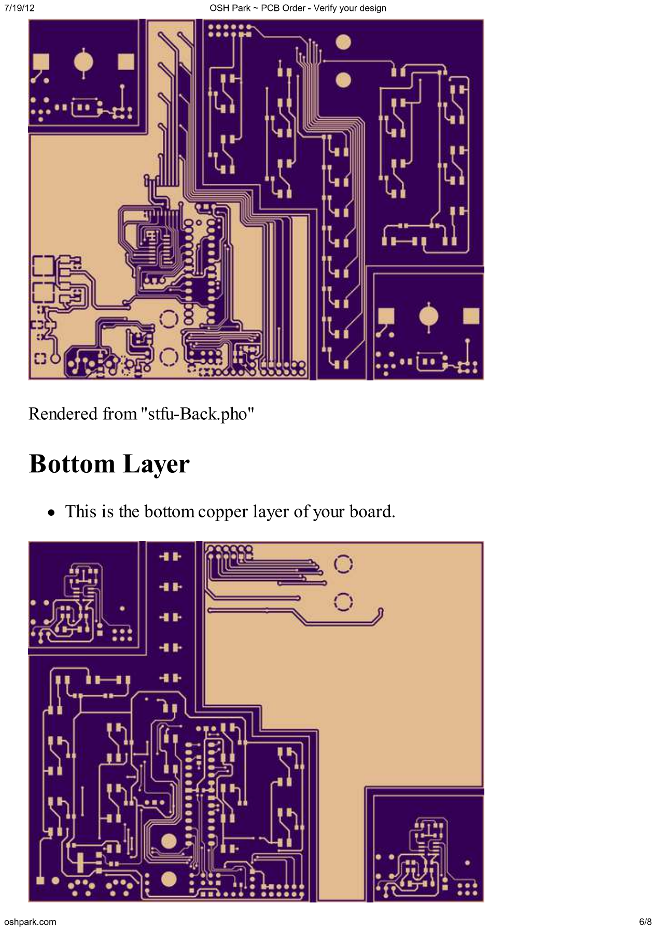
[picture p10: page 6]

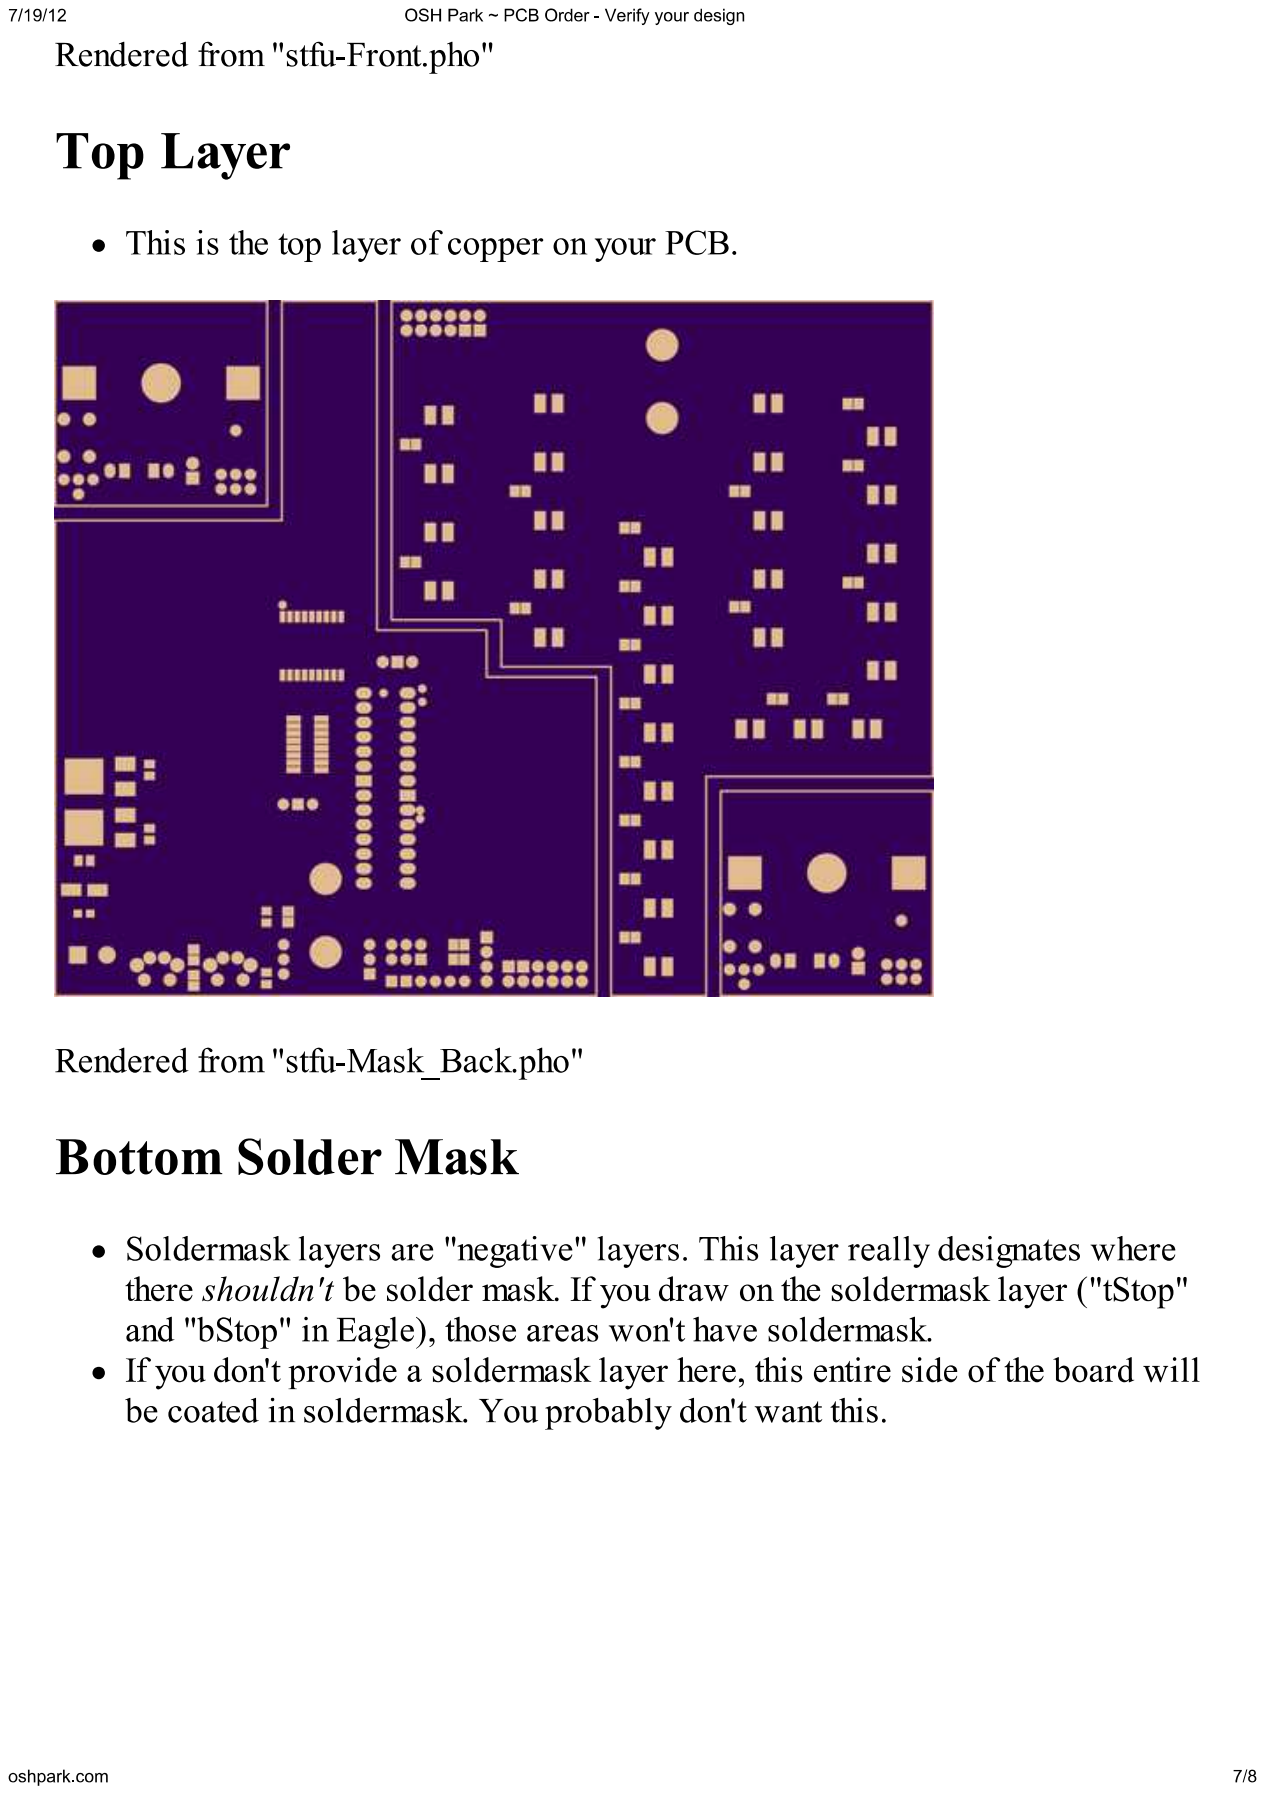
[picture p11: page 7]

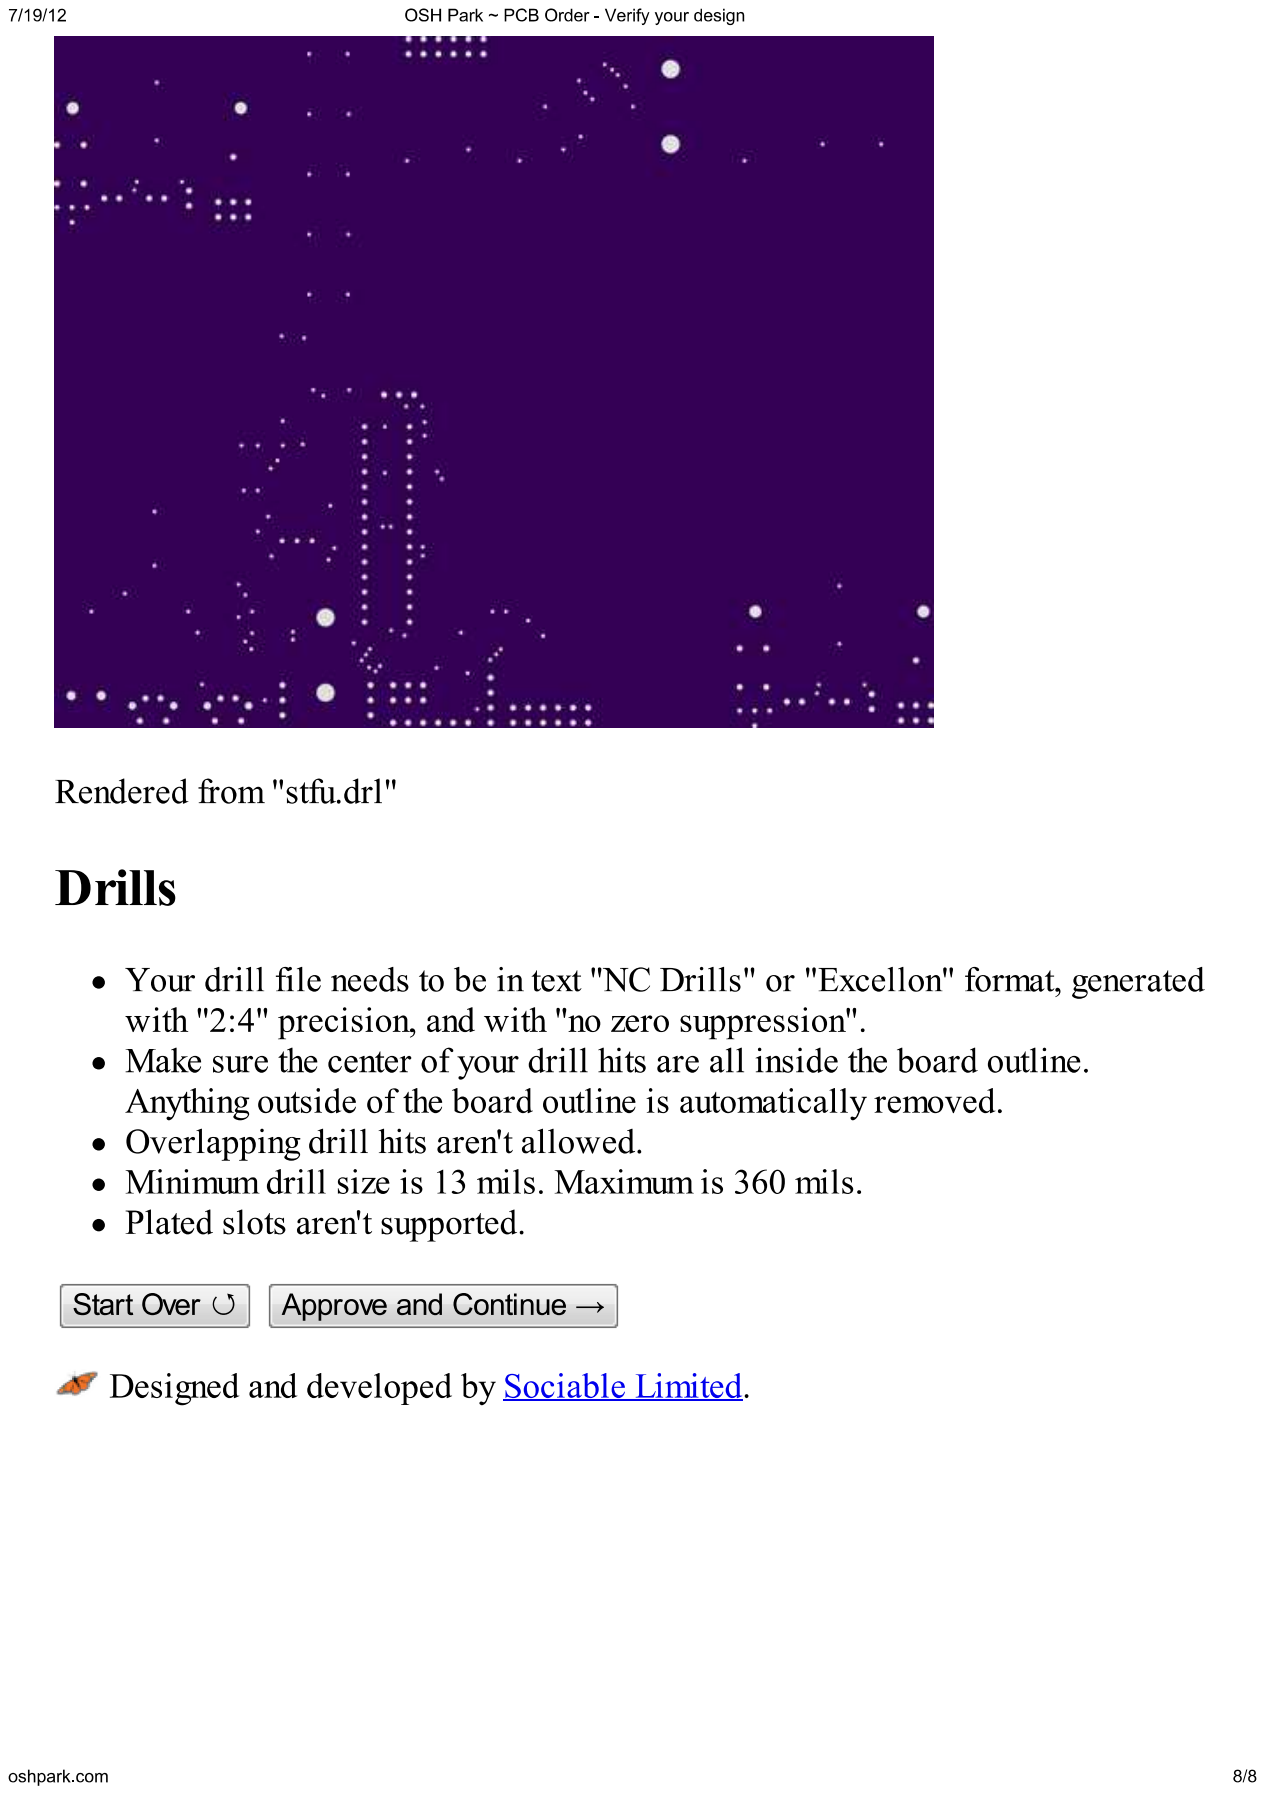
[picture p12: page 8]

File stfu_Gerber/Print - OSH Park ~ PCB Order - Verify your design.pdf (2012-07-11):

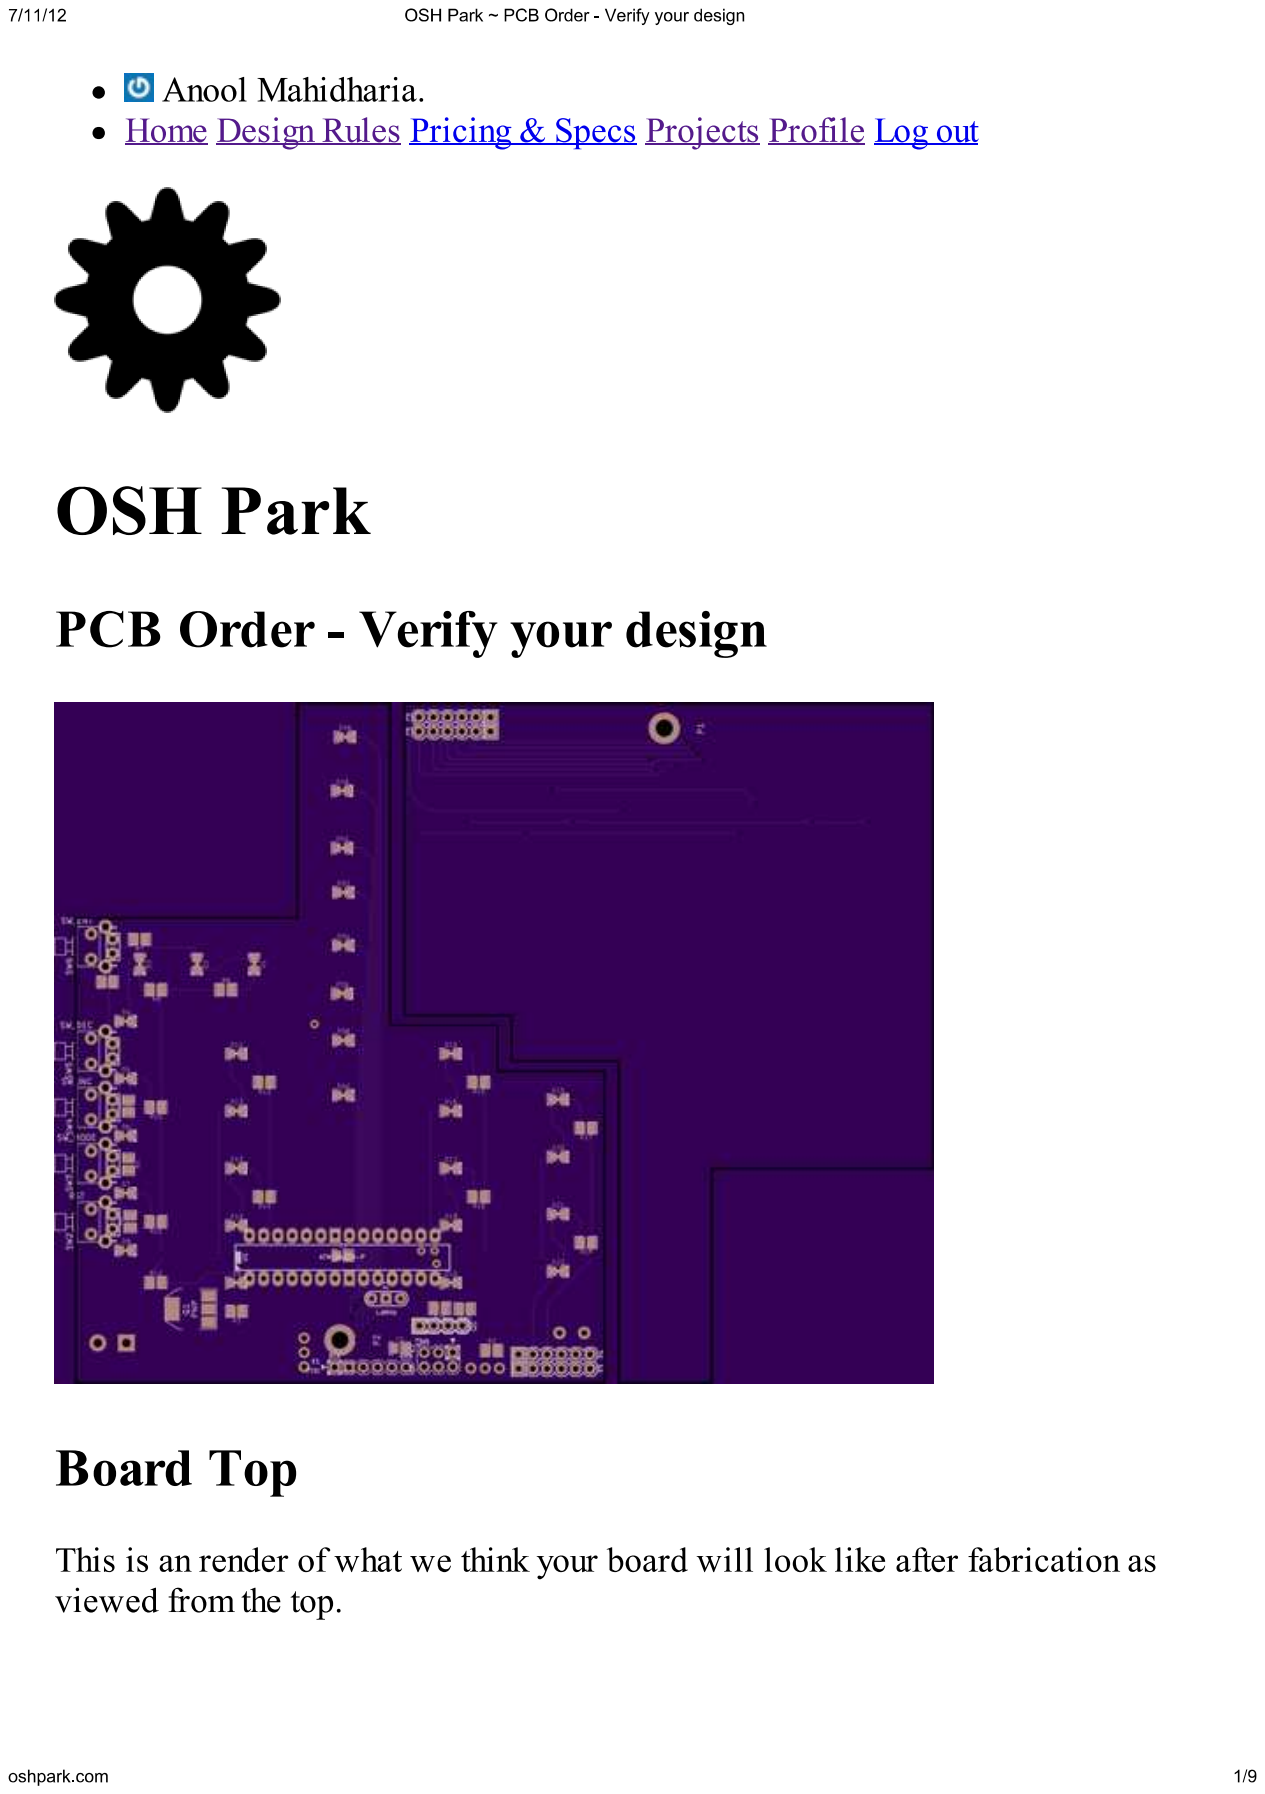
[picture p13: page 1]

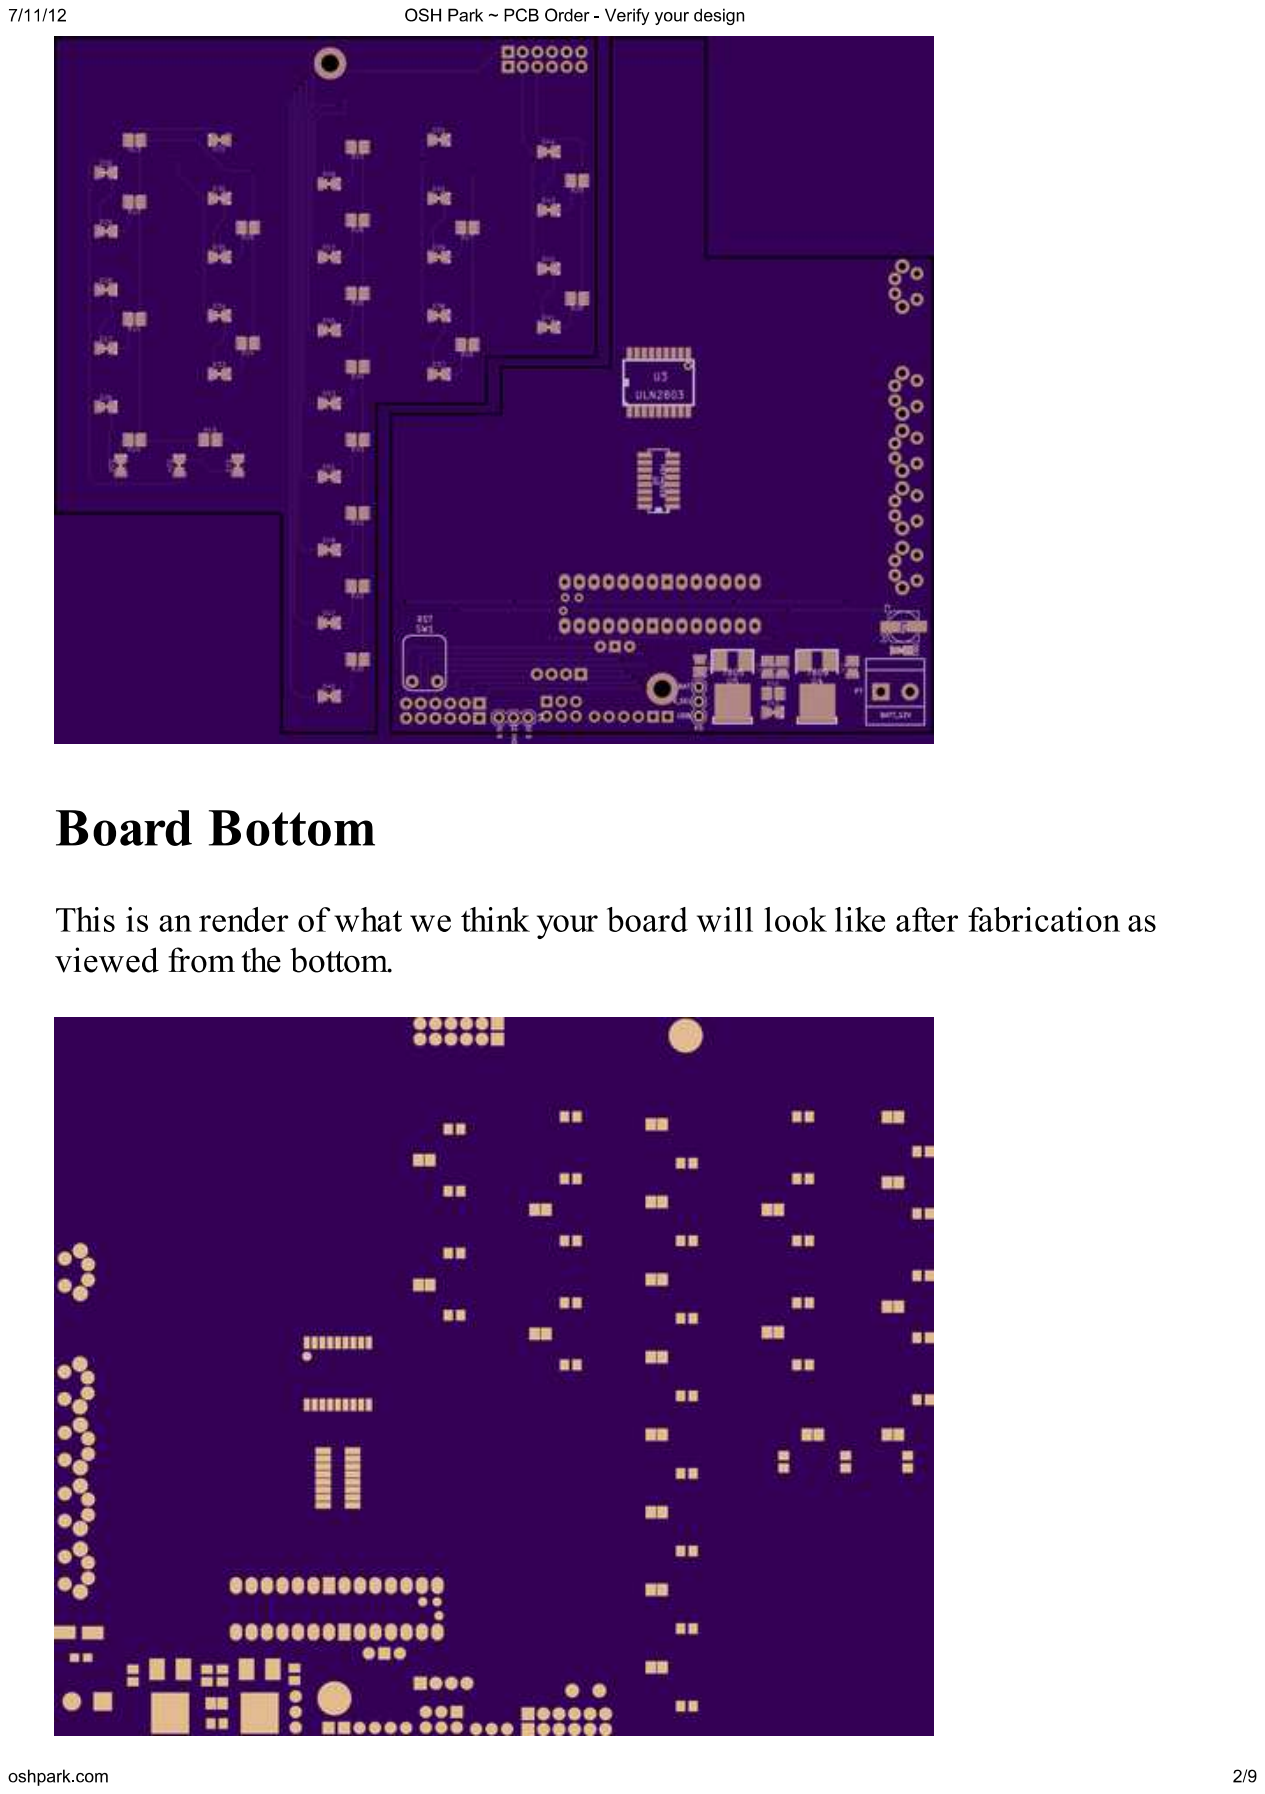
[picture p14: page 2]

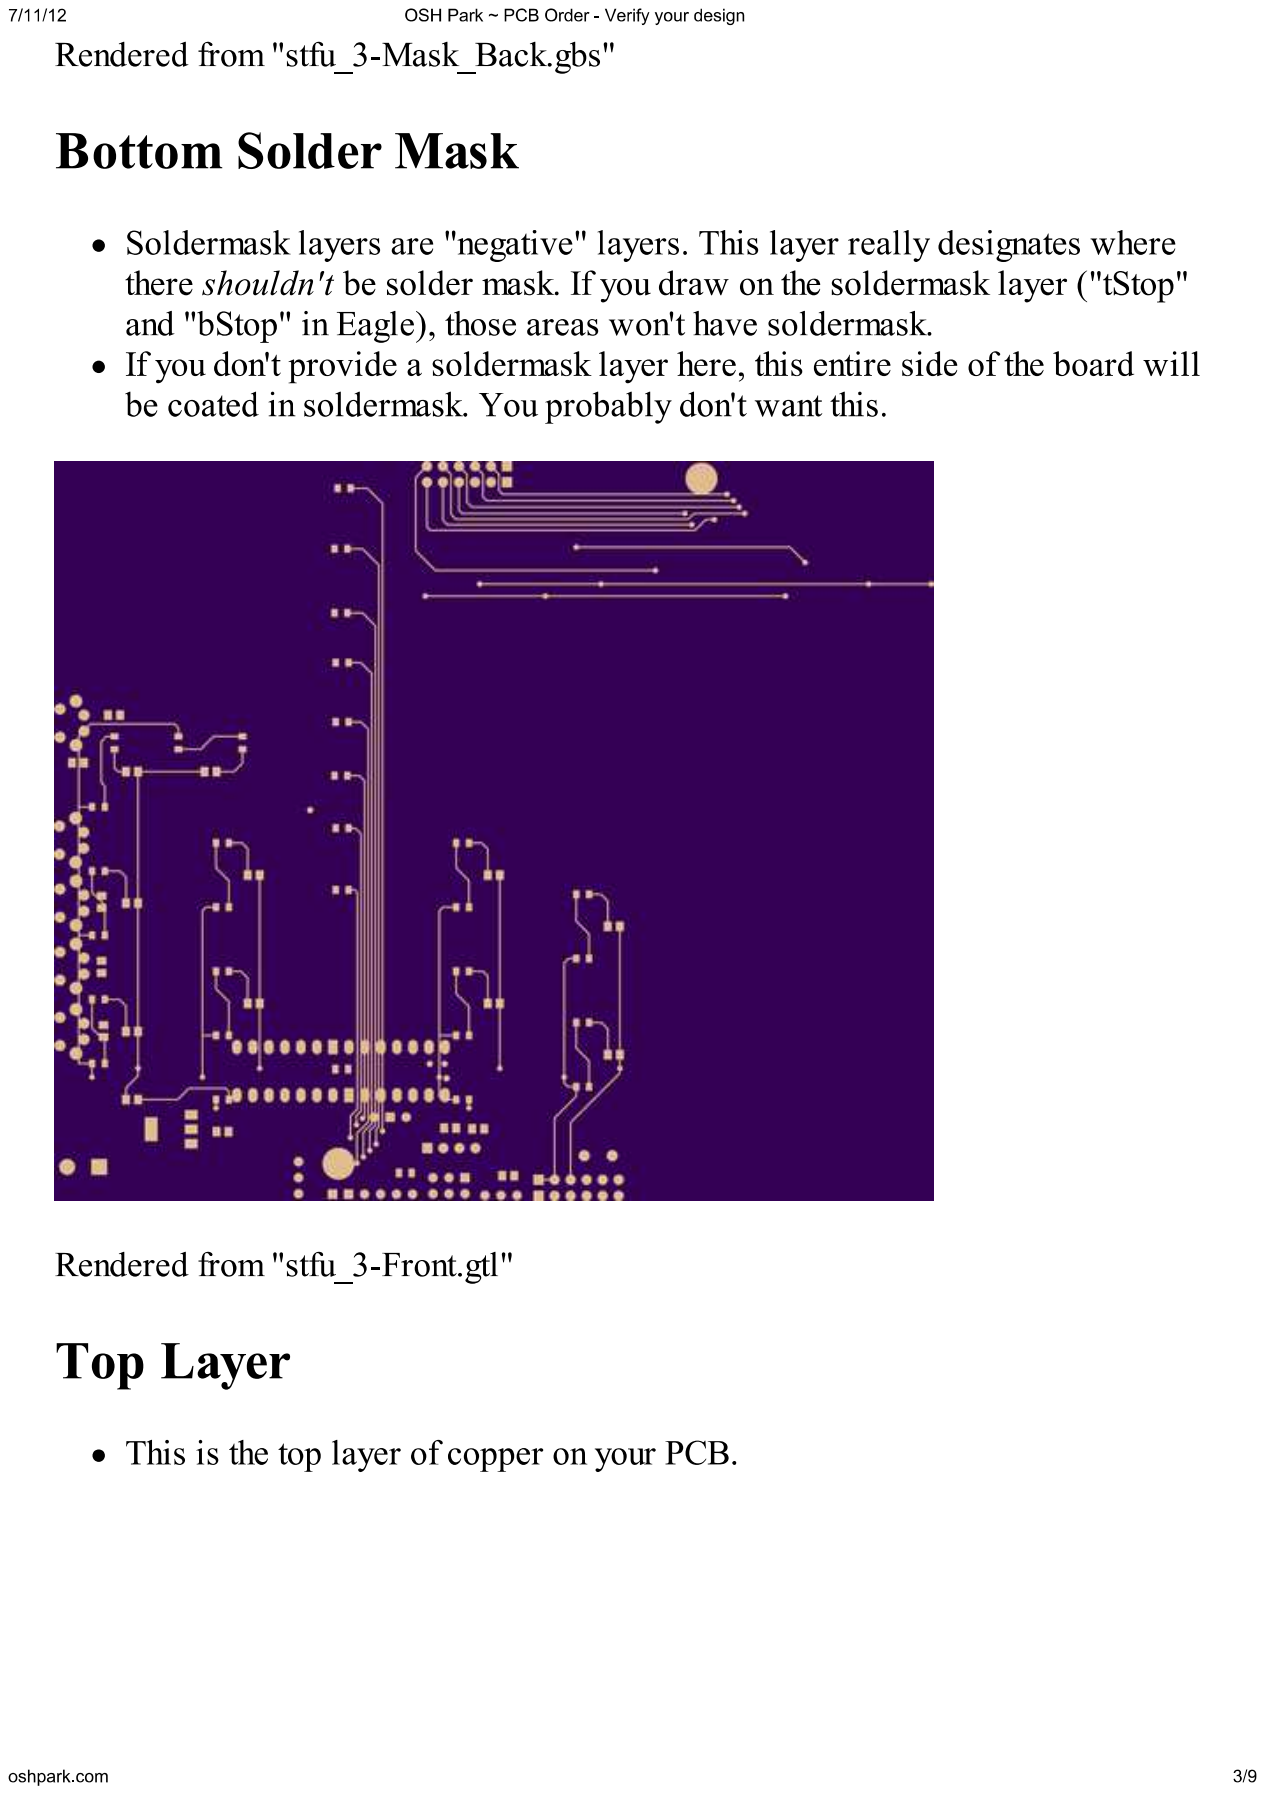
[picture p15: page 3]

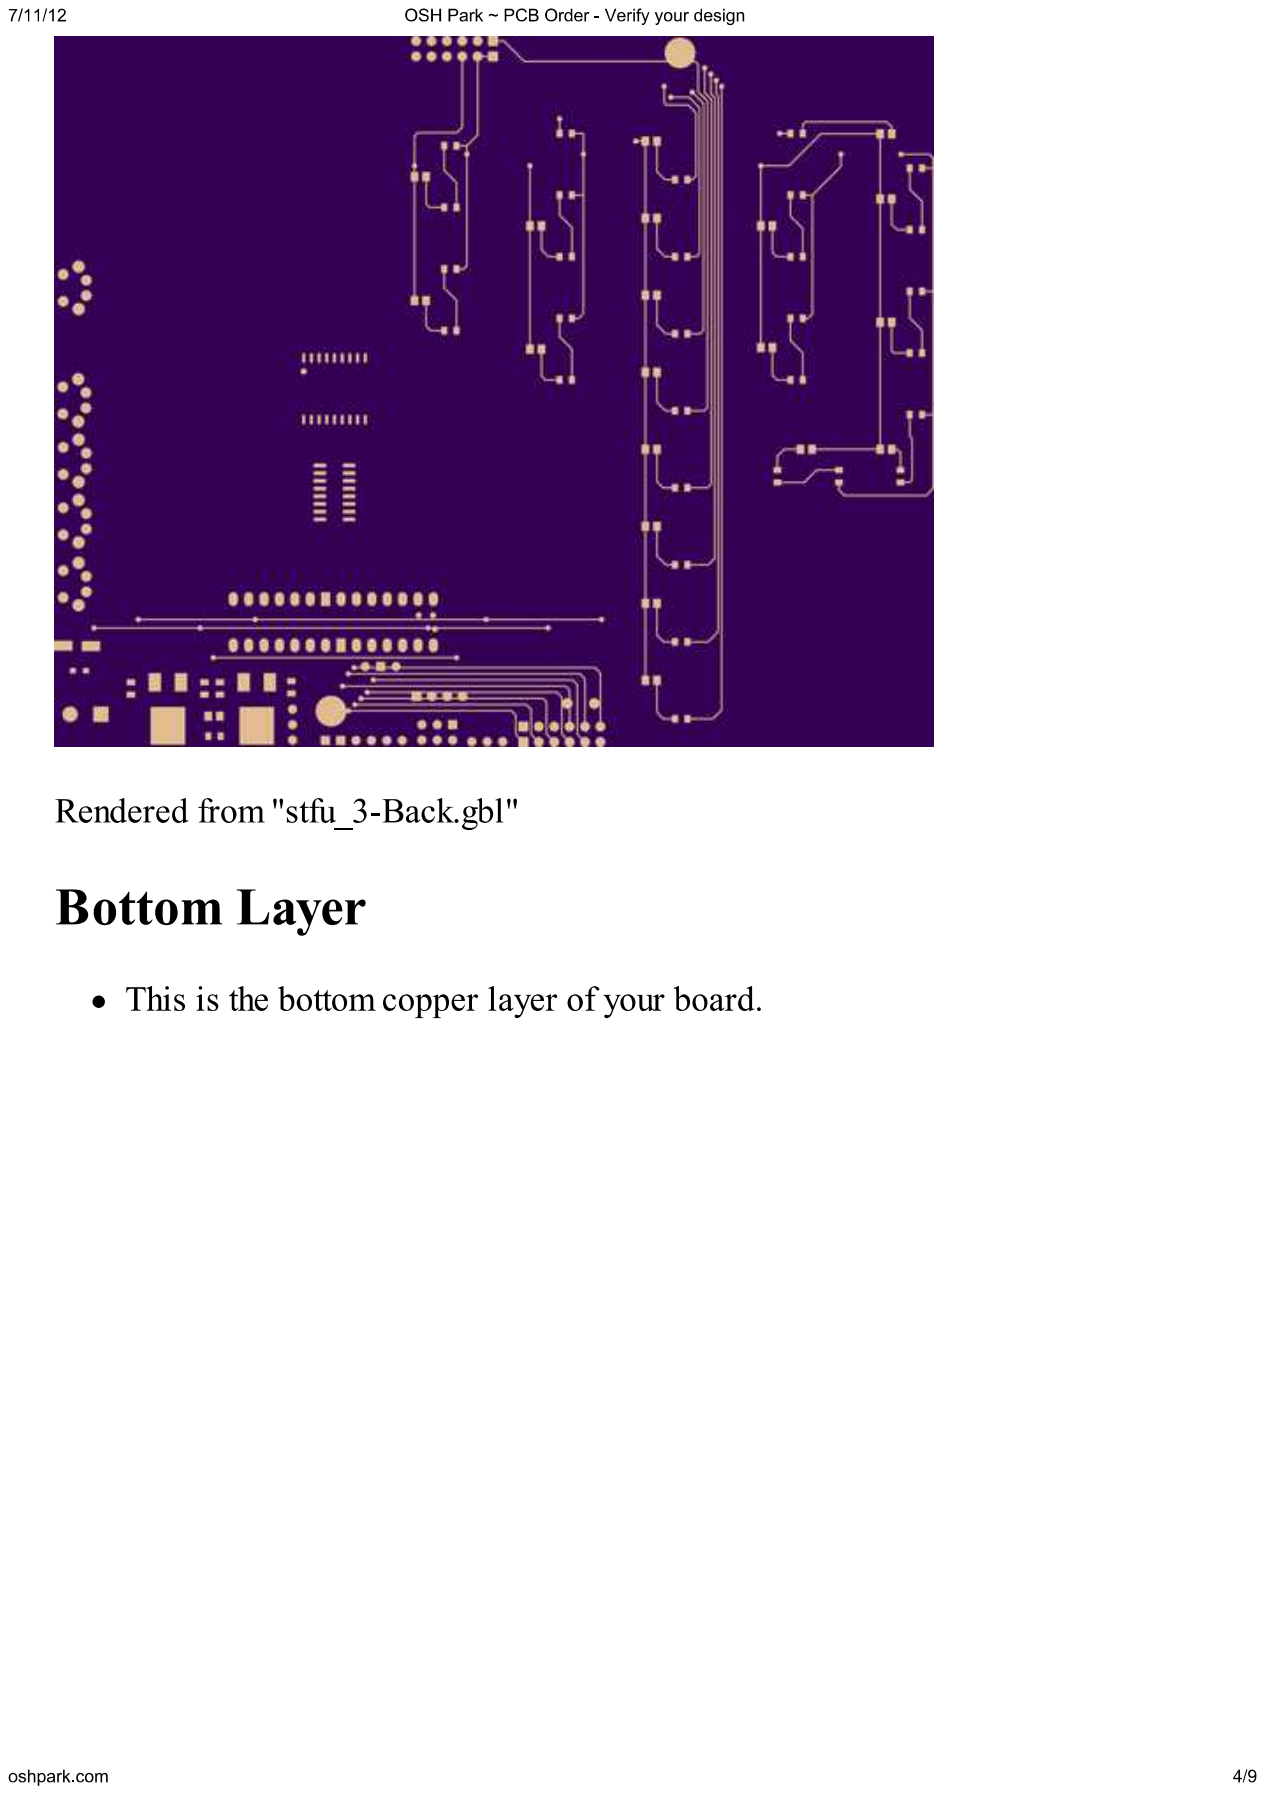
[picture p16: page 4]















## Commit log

2012-07-04 Initial commit of STFU KiCad design files
    [BoM_sch_stfu.csv, stfu.sch]
2012-07-04 initial project version of STFU, KiCad files
2012-07-04 first commit of STFU KiCad files
2012-07-04 added the KiCad design files for STFU
    [BoM_sch_stfu.csv, stfu.sch]
2012-07-05 added a hearchical sheet for the "other hand"
    [other_hand.sch]
2012-07-05 added the second Hand
    [BoM_sch_stfu.csv, other_hand.sch, stfu.sch]
2012-07-07 added module libraried, 3d render files
    [stfu.brd]
2012-07-08 preliminary board layout
    [$savepcb.brd, other_hand.sch, stfu.brd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]
2012-07-09 board, work in progress, #1
    [stfu.brd]
2012-07-09 board layout, work in progress.
    [$savepcb.brd, other_hand.sch, stfu.brd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]
2012-07-10 STFU board layout - work in progress
    [other_hand.sch, stfu.brd, stfu.sch]
2012-07-10 Board layout, work in progress
    [$savepcb.brd, other_hand.sch, stfu.brd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]
2012-07-11 updated schematic pdf
    [BoM_sch_stfu.csv]
2012-07-11 added detailed BoM (Parts List) with costs
    [$stfu.brd, BoM_pcb_stfu.csv, BoM_stfu.ods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]
2012-07-12 WiP, board layout progressing. Added IR receiver, removed a few buttons.
    [BoM_sch_stfu.csv, other_hand.sch, stfu.brd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]
2012-07-12 WiP, board layout, 185 tracks done, 49 more to go
    [$savepcb.brd, other_hand.sch, stfu.brd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]
2012-07-13 WiP - Board layout complete. Someone needs to verify it all.
    [BoM_pcb_stfu.csv, stfu.brd, stfu.dsn]
2012-07-13 WiP, changed LED & Q1 package. Need to modify track layout.
    [BoM_stfu.ods, stfu.brd]
2012-07-16 WiP, changed LED footpint. changed location of switches.
    [stfu.brd]
2012-07-16 WiP, track optimization
    [$savepcb.brd, other_hand.sch, stfu.brd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]
2012-07-17 WiP, board layout complete, Legends done, final verification required
    [BoM_pcb_stfu.csv, BoM_sch_stfu.csv, other_hand.sch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]
2012-07-17 WiP, Modified Parts List
    [BoM_stfu.ods, BoM_stfu_DigiKey.xls, BoM_stfu_Mouser.xls]
2012-07-18 WiP - decided to add a IR Transmitter in the spare available board space.
    [BoM_pcb_stfu.csv, BoM_sch_stfu.csv, BoM_stfu.ods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]
2012-07-18 WiP, added IR Tx parts on PCB.
    [BoM_stfu.ods, IR_Tx.sch, other_hand.sch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]
2012-07-19 WiP : STFU Ir Transmitter complete. BoM updated.
    [BoM_pcb_stfu.csv, BoM_stfu.ods, BoM_stfu_DigiKey.csv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]
2012-07-19 WiP - Silk legend mods.
    [$savepcb.brd, stfu.brd]
2012-07-21 WiP - track cleanup and optimization, Legend clean up etc.
    [BoM_pcb_stfu.csv, BoM_sch_stfu.csv, BoM_stfu.ods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]
